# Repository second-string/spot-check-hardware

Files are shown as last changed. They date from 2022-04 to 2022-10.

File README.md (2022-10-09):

# spot-check-hardware
Board design and assembly files for the Spot Check project

* Firmware repo: https://github.com/dot4qu/spot-check-firmware
* Backend API repo: https://github.com/dot4qu/spot-check-api
* Configuration iOS app repo: https://github.com/dot4qu/spot-check-ios

More pictures of overall enclosure and project found in the firmware repo.

## Rev 3.1

**Use this version!!**

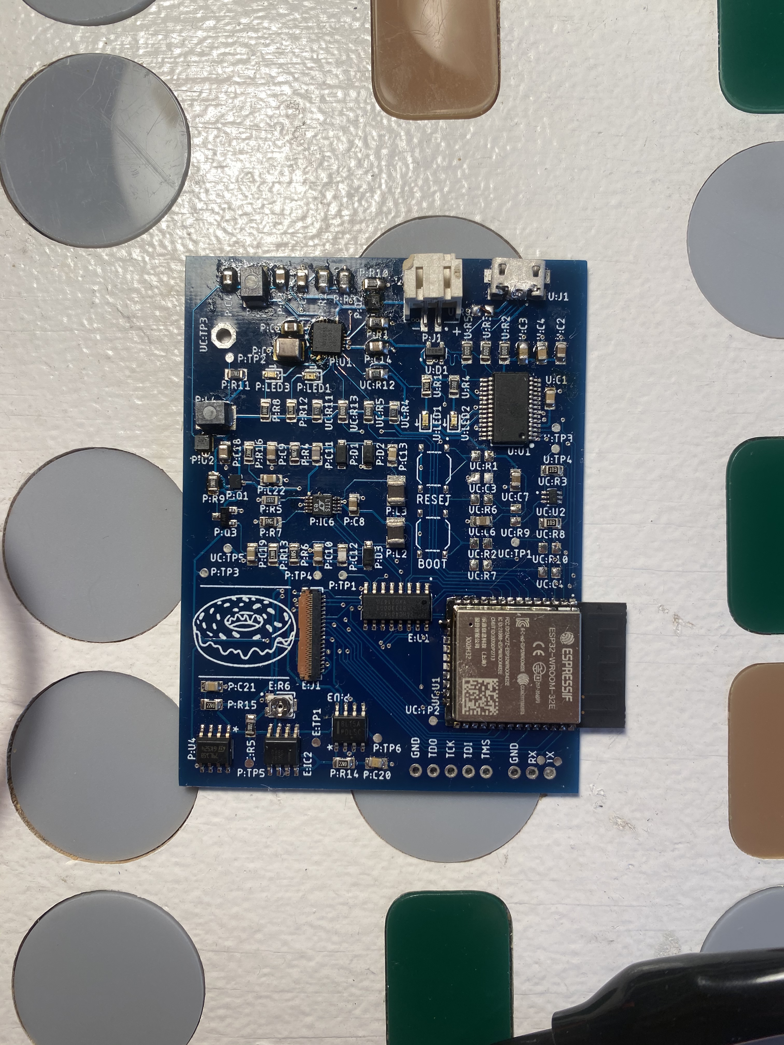
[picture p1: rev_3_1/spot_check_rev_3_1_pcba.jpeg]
Spot Check rev. 3.1 PCBA


Fixes the issues in rev 3, mainly:
* Adds the missing capacitor between BTST and SW output of BQ24196 battery charger
* Switches the ESP footprint to the correct ESP32-WROVER footprint (all I/O on sides and longer length, no I/O on bottom like WROOM)
* Add 1uF cap acros ESP32 EN pin to slow its rise time enough to allow DTR/RTS auto-programming circuit to work
* Removed all the now-unneccesary zero ohm resistors

## Rev 3

_See rev. 3.1 PCBA, only minor differences_

Huge rework and addition from rev 2. Adds:
* USB to UART IC for power and programming instead of UART header (still on board for backup use if needed)
* Battery charger IC for supporting battery powered operation instead of wall outlet power
* Integrated e-ink driver circuit using shift register, boost converter to produce +22/-20V, additional regulators to filter to +/-15V, and a small-pitch FPC connector to connect to e-ink display
* Switch to ESP32-WROVER for additional on-module SRAM needed to run `epdiy` open source e-ink firmware

## Rev 2

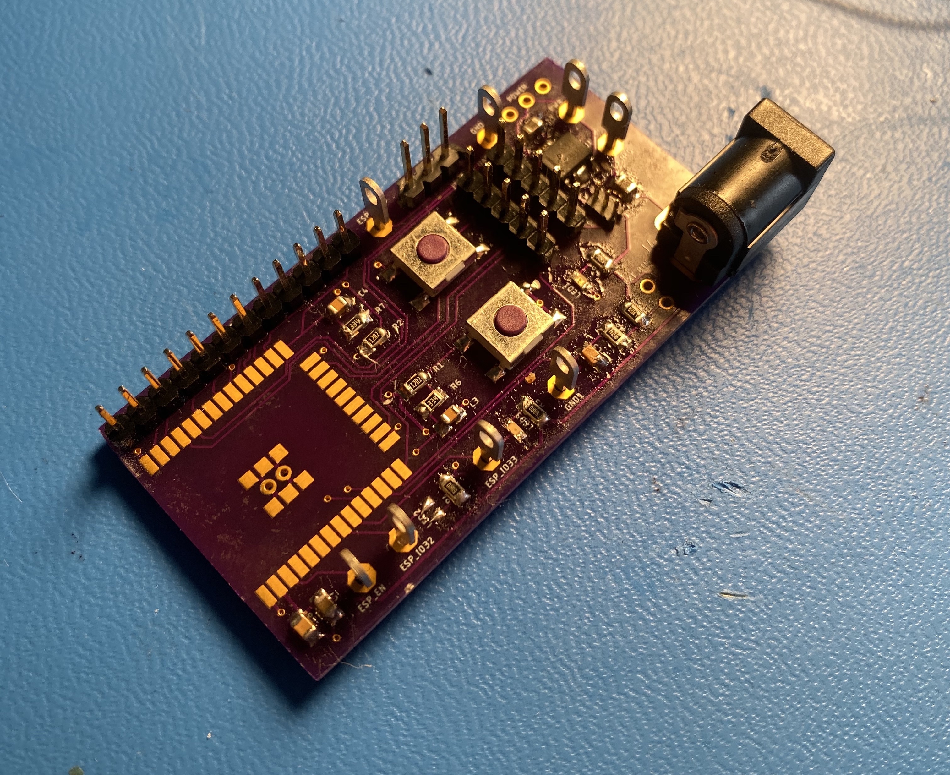
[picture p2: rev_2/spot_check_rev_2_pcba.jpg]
Spot Check rev. 2 PCBA


The main, working revision for properly displaying text on an LED strip ticker with only an ESP32 driving everything. Powered from a 5V 1.5A+ barrel jack.

## Rev 1

Spot Check rev. 1 PCBA

The OG. This was an ESP chip that ran the main application logic that then communicated serially over UART to an ATMega328p to display the text on the LED strips (as the LED text libraries are only developed for Arduino). Zero support for this, I don't think I ever got the serial communication working super well since I had no protocol and the ESP would spew nonsense signals on boot. Oh to be young and naive again (just kidding I still am).

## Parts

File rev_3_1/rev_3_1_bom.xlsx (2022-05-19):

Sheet: BOM
Spot Check
Project: | Spot Check |  |  |  | Do not have enough in stock
Revision | 3 |  |  |  | Have exactly the right amount in stock
File created: | 2022-02-05 |  |  |  | Have extra stock
Bill of Materials
Mfg. Part Number | Description | Source | Link | Current stock | Have enough | Quantity | Measurement | Unit Price | Total Price | Filtered search URL | Notes
ED060SC4 | e-ink display | ebay |  |  | -1 | 1 |  | $25.00 | $25.00
SKU: 9067000191-0 | 2000MAH 1S/1C LiPo w/ 2 pin JST-PH conn. | HobbyKing | https://hobbyking.com/en_us/turnigy-2000mah-1s-1c-lipoly-w-2-pin-jst-ph-connector.html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 |  | -1 | 1 |  | $4.53 | $4.53 | Second hobbyking order: https://hobbyking.com/en_us/turnigy-1200mah-1s-1c-lipoly-w-2-pin-jst-ph-connector.html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 Another option (expensive, w/ TS & UL cert): https://www.batteryspace.com/Polymer-Li-Ion-battery-3.7V-2000mAh-7.4-Wh-with-10K-NTC.aspx
BQ24196RGER | Battery charger IC VQFN | Digikey | https://www.digikey.com/en/products/detail/texas-instruments/BQ24196RGER/3902488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 |  | -1 | 1 |  | $4.04 | $4.04 | https://www.ti.com/power-management/battery-management/charger-ics/products.html | Have second pin-compatible alternate in stock too
TPS62082DSGR | 3.3V buck | Digikey | https://www.digikey.com/en/products/detail/texas-instruments/TPS62082DSGR/2797959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 |  | -1 | 1 |  | $1.73 | $1.73
MC78L15ACDR2G | 15V linear reg | Digikey | https://www.digikey.com/en/products/detail/onsemi/MC78L15ACDR2G/919359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 |  | -1 | 1 |  | $0.53 | $0.53
L79L15ABD13TR | neg 15 linear reg | Digikey | https://www.digikey.com/en/products/detail/stmicroelectronics/L79L15ABD13TR/1038332 |  | -1 | 1 |  | $0.51 | $0.51 | https://www.digikey.com/en/products/filter/pmic-voltage-regulators-linear/699 | Main desired part (OOS, alternative in BOM): MC79L15ACDR2G/MC79L15ABDR2G
SSM3J132TU,LF | P-channel FET | Digikey | https://www.digikey.com/en/products/detail/toshiba-semiconductor-and-storage/SSM3J132TU-LF/6198762 |  | -2 | 2 |  | $0.54 | $1.08 | https://www.digikey.com/en/products/filter/transistors-fets-mosfets-single/278 | This could be less $, went for super low Rds for low V burn from batt
ESP32-WROVER-32E | ESP32 WROVER 8MB flash w/ PCB antenna | Digikey | https://www.digikey.com/en/products/detail/espressif-systems/ESP32-WROVER-E-N8R8/11613126 |  | -1 | 1 |  | $3.60 | $3.60
MBR0520LT1G | Boost converter diodes | Digikey | https://www.digikey.com/en/products/detail/onsemi/MBR0520LT1G/918574?s=N4IgTCBcDaILICEBKAGArGFAZAKgRgHEQBdAXyA |  | -3 | 3 |  | $0.36 | $1.08
DRTR5V0U2SR-7 | USB TVS package | Digikey | https://www.digikey.com/en/products/detail/diodes-incorporated/DRTR5V0U2SR-7/4402528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 |  | -1 | 1 |  | $0.40 | $0.40
LM358DR | 2 channel op-amp | Digikey | https://www.digikey.com/en/products/detail/texas-instruments/LM358DR/276658 |  | -1 | 1 |  | $0.69 | $0.69 |  | Identical part (diff. distrib., more $) if sold out: https://www.digikey.com/en/products/detail/rohm-semiconductor/LM358DR/1878967
LT1945EMS#PBF | Boost converter | Digikey | https://www.digikey.com/en/products/detail/analog-devices-inc/LT1945EMS-PBF/890537 |  | -1 | 1 |  | $6.21 | $6.21 |  | This price is fucked, alternate part or other supplier
PTS526 SK15 SMTR2 LFS | SMD button | Digikey | https://www.digikey.com/en/products/detail/c-k/PTS526-SK15-SMTR2-LFS/10056626 |  | -2 | 2 |  | $0.11 | $0.22 | https://www.digikey.com/en/products/filter/tactile-switches/197
74HC4094D,653 | Shift and store register | Digikey | https://www.digikey.com/en/products/detail/nexperia-usa-inc/74HC4094D-653/946727 |  | -1 | 1 |  | $0.52 | $0.52
FT232RL | USB to serial transceiver | ebay |  |  | -1 | 1 |  | $3.00 | $3.00
MMBT3904,215 | NPN BJT | Digikey | https://www.digikey.com/en/products/detail/nexperia-usa-inc/MMBT3904-215/1156599 |  | -1 | 1 |  | $0.12 | $0.12
BC848CDW1T1G | 2 NPN BJT package | Digikey | https://www.digikey.com/en/products/detail/onsemi/BC848CDW1T1G/1476035 |  | -1 | 1 |  | $0.26 | $0.26
10118192-0002LF | USB micro female SMT right-angle connector | Digikey | https://www.digikey.com/en/products/detail/amphenol-icc-fci/10118192-0002LF/6817756 |  | -1 | 1 |  | $0.44 | $0.44 |  | Alternate: https://www.digikey.com/en/products/detail/amphenol-cs-fci/10118192-0001LF/2785387
FH26W-39S-0.3SHW(60) | 39 pin SMD flex connector | Digikey | https://www.digikey.com/en/products/detail/hirose-electric-co-ltd/FH26W-39S-0-3SHW-60/5132503 |  | -1 | 1 |  | $1.92 | $1.92
JST-PHR-2 | Male 2-pin JST connector | Digikey | https://www.digikey.com/en/products/detail/jst-sales-america-inc/S2B-PH-K-S-LF-SN/926626 |  | -1 | 1 |  | $0.17 | $0.17 | sold out everwhere
150060GS75000 | 0603 green LED for BQ | Digikey | https://www.digikey.com/en/products/detail/würth-elektronik/150060GS75000/4489898 |  | -1 | 1 |  | $0.15 | $0.15 | https://www.digikey.com/en/products/filter/led-indication-discrete/105
150060RS75000 | 0603 red LED for BQ | Digikey | https://www.digikey.com/en/products/detail/würth-elektronik/150060RS75000/4489901 |  | -1 | 1 |  | $0.15 | $0.15
150060BS75000 | 0603 blue LED for FT232 | Digikey | https://www.digikey.com/en/products/detail/würth-elektronik/150060BS75000/4489895 |  | -1 | 1 |  | $0.16 | $0.16
150060YS75000 | 0603 yellow LED for FT232 | Digikey | https://www.digikey.com/en/products/detail/würth-elektronik/150060YS75000/4489909 |  | -1 | 1 |  | $0.15 | $0.15
PREC040SAAN-RC | Male 0.1" 40 position header (default unpop.) | Digikey | https://www.digikey.com/en/products/detail/sullins-connector-solutions/PREC040SAAN-RC/2774814 |  | -1 | 1 |  | $0.51 | $0.51 | https://www.digikey.com/en/products/filter/rectangular-connectors-headers-male-pins/314 | Need 8 to fully populate JTAG and backup UART breakout
CL21B104KBCNFNC | 0.1uF 0805 ceramic capacitor for max 22V | Digikey | https://www.digikey.com/en/products/detail/samsung-electro-mechanics/CL21B104KBCNFNC/3888102 |  | -5 | 5 |  | $0.10 | $0.50 | ^
CL21B334KBFNNNE | 0.33uF 0805 ceramic capacitor for max 22V | Digikey | https://www.digikey.com/en/products/detail/samsung-electro-mechanics/CL21B334KBFNNNE/3886781 |  | -2 | 2 |  | $0.10 | $0.20 | https://www.digikey.com/en/products/filter/ceramic-capacitors/60
CL21B105KAFNNNE | 1uF 0805 ceramic capacitor for max 5V | Digikey | https://www.digikey.com/en/products/detail/samsung-electro-mechanics/CL21B105KAFNNNE/3886724 |  | -3 | 3 |  | $0.10 | $0.30 | https://www.digikey.com/en/products/filter/ceramic-capacitors/60
CL21B105KBFNNNG | 1uF 0805 ceramic capacitor for max 22V | Digikey | https://www.digikey.com/en/products/detail/samsung-electro-mechanics/CL21B105KBFNNNG/3894467 |  | -2 | 2 |  | $0.12 | $0.24 | https://www.digikey.com/en/products/filter/ceramic-capacitors/60
CC0805BRNPO9BN4R7 | 4.7pF 0805 ceramic capacitor for max 22V | Digikey | https://www.digikey.com/en/products/detail/yageo/CC0805BRNPO9BN4R7/5883879 |  | -1 | 1 |  | $0.17 | $0.17
CL21A475KAQNNNG | 4.7uF 0805 ceramic capacitor for max 5V | Digikey | https://www.digikey.com/en/products/detail/samsung-electro-mechanics/CL21A475KAQNNNG/3894439 |  | -3 | 3 |  | $0.11 | $0.33 | https://www.digikey.com/en/products/filter/ceramic-capacitors/60
CGA6P3X7R1E685K250AB | 6.8uF 0805 ceramic capacitor for max 5V | Digikey | https://www.digikey.com/en/products/detail/tdk-corporation/CGA6P3X7R1E685K250AB/2443197 |  | -1 | 1 |  | $0.70 | $0.70 | https://www.digikey.com/en/products/filter/ceramic-capacitors/60
CL21B103KAANNNC | 10nF 0805 ceramic capacitor for max 5V | Digikey | https://www.digikey.com/en/products/detail/samsung-electro-mechanics/CL21B103KAANNNC/3888092 |  | -1 | 1 |  | $0.10 | $0.10 | https://www.digikey.com/en/products/filter/ceramic-capacitors/60
CL21A106KOQNNNE | 10uF 0805 ceramic capacitor for max 3V3 | Digikey | https://www.digikey.com/en/products/detail/samsung-electro-mechanics/CL21A106KOQNNNE/3886754 |  | -3 | 3 |  | $0.11 | $0.33 | https://www.digikey.com/en/products/filter/ceramic-capacitors/60
CL21A226KOQNNNG | 22uF 0805 ceramic capacitor for max 3V3 | Digikey | https://www.digikey.com/en/products/detail/samsung-electro-mechanics/CL21A226KOQNNNG/3894433 |  | -2 | 2 |  | $0.35 | $0.70 | https://www.digikey.com/en/products/filter/ceramic-capacitors/60
CL21C101JBANFNC | 100pF 0805 ceramic capacitor for max 22V | Digikey | https://www.digikey.com/en/products/detail/samsung-electro-mechanics/CL21C101JBANFNC/3888226 |  | -1 | 1 |  | $0.10 | $0.10
CL21B473KCFNNNE | 47nF 0805 ceramic capacitor for max 5V | Digikey | https://www.digikey.com/en/products/detail/samsung-electro-mechanics/CL21B473KCFNNNE/3888618 |  | -1 | 1 |  | $0.10 | $0.10 | https://www.digikey.com/en/products/filter/ceramic-capacitors/60
TC33X-1-103E | 10k ohm SMT potentiometer | Digikey | https://www.digikey.com/en/products/detail/bourns-inc/TC33X-1-103E/2566867 |  | -1 | 1 |  | $0.26 | $0.26 | https://www.digikey.com/en/products/detail/nidec-copal-electronics/ST4ETB103/738213 | Can just replace footprint with correctly sized resistor for screen's VCOM in the future
RMCF0805FT1K20 | 1.2k ohm 0805 resistor | Digikey | https://www.digikey.com/en/products/detail/stackpole-electronics-inc/RMCF0805FT1K20/1760625 |  | -2 | 2 |  | $0.10 | $0.20 | https://www.digikey.com/en/products/filter/chip-resistor-surface-mount/52
RMCF0805FT2K20 | 2.2k ohm 0805 resistor | Digikey | https://www.digikey.com/en/products/detail/stackpole-electronics-inc/RMCF0805FT2K20/1760345 |  | -1 | 1 |  | $0.10 | $0.10 | https://www.digikey.com/en/products/filter/chip-resistor-surface-mount/52
RMCF0805JT1M00 | 1M ohm 0805 resistor | Digikey | https://www.digikey.com/en/products/detail/stackpole-electronics-inc/RMCF0805JT1M00/1757878 |  | -1 | 1 |  | $0.10 | $0.10 | https://www.digikey.com/en/products/filter/chip-resistor-surface-mount/52
RMCF0805JT4K70 | 4.7k ohm 0805 resistor | Digikey | https://www.digikey.com/en/products/detail/stackpole-electronics-inc/RMCF0805JT4K70/1757774 |  | -3 | 3 |  | $0.10 | $0.30 | https://www.digikey.com/en/products/filter/chip-resistor-surface-mount/52
RMCF0805JT10K0 | 10k ohm 0805 resistor | Digikey | https://www.digikey.com/en/products/detail/stackpole-electronics-inc/RMCF0805JT10K0/1757762 |  | -2 | 2 |  | $0.10 | $0.20 | https://www.digikey.com/en/products/filter/chip-resistor-surface-mount/52
RMCF0805FT12K0 | 12k ohm 0805 resistor | Digikey | https://www.digikey.com/en/products/detail/stackpole-electronics-inc/RMCF0805FT12K0/1760674 |  | -2 | 2 |  | $0.10 | $0.20 | https://www.digikey.com/en/products/filter/chip-resistor-surface-mount/52
RMCF0805FT20K0 | 20k ohm 0805 resistor | Digikey | https://www.digikey.com/en/products/detail/stackpole-electronics-inc/RMCF0805FT20K0/1760314 |  | -1 | 1 |  | $0.10 | $0.10 | https://www.digikey.com/en/products/filter/chip-resistor-surface-mount/52
RMCF0805FT22R0 | 22 ohm 0805 resistor | Digikey | https://www.digikey.com/en/products/detail/stackpole-electronics-inc/RMCF0805FT22R0/1712862 |  | -4 | 4 |  | $0.10 | $0.40 | https://www.digikey.com/en/products/filter/chip-resistor-surface-mount/52
RMCF0805FT26K1 | 26.1k ohm 0805 resistor | Digikey | https://www.digikey.com/en/products/detail/stackpole-electronics-inc/RMCF0805FT26K1/1760232 |  | -2 | 2 |  | $0.10 | $0.20 | https://www.digikey.com/en/products/filter/chip-resistor-surface-mount/52
RMCF0805FT59K0 | 59k ohm 0805 resistor | Digikey | https://www.digikey.com/en/products/detail/stackpole-electronics-inc/RMCF0805FT59K0/1760440 |  | -1 | 1 |  | $0.10 | $0.10 | https://www.digikey.com/en/products/filter/chip-resistor-surface-mount/52
RMCF0805FT178K | 178k ohm 0805 resistor | Digikey | https://www.digikey.com/en/products/detail/stackpole-electronics-inc/RMCF0805FT178K/1712751 |  | -1 | 1 |  | $0.10 | $0.10 | https://www.digikey.com/en/products/filter/chip-resistor-surface-mount/52
RMCF0805FT270R | 270 ohm 0805 resistor | Digikey | https://www.digikey.com/en/products/detail/stackpole-electronics-inc/RMCF0805FT270R/1760099 |  | -1 | 1 |  | $0.10 | $0.10 | https://www.digikey.com/en/products/filter/chip-resistor-surface-mount/52
RMCF0805FT330R | 330 ohm 0805 resistor | Digikey | https://www.digikey.com/en/products/detail/stackpole-electronics-inc/RMCF0805FT330R/1760484 |  | -1 | 1 |  | $0.10 | $0.10 | https://www.digikey.com/en/products/filter/chip-resistor-surface-mount/52
RMCF0805FT330K | 330k ohm 0805 resistor | Digikey | https://www.digikey.com/en/products/detail/stackpole-electronics-inc/RMCF0805FT330K/1760482 |  | -2 | 2 |  | $0.10 | $0.20 | https://www.digikey.com/en/products/filter/chip-resistor-surface-mount/52
RMCF0805FT402K | 402k ohm 0805 resistor | Digikey | https://www.digikey.com/en/products/detail/stackpole-electronics-inc/RMCF0805FT402K/1713128 |  | -1 | 1 |  | $0.10 | $0.10 | https://www.digikey.com/en/products/filter/chip-resistor-surface-mount/52
RMCF0805JG470R | 470 ohm 0805 resistor | Digikey | https://www.digikey.com/en/products/detail/stackpole-electronics-inc/RMCF0805JG470R/1712020 |  | -1 | 1 |  | $0.10 | $0.10 | https://www.digikey.com/en/products/filter/chip-resistor-surface-mount/52
CBC3225T220KR | 22uH 1280 10% 580mA inductor | Digikey | https://www.digikey.com/en/products/detail/taiyo-yuden/CBC3225T220KR/2763319 |  | -2 | 2 |  | $0.30 | $0.60 | https://www.digikey.com/en/products/filter/fixed-inductors/71
B82432T1222K000 | 2.2uH SMD-2 10% 1A inductor | Digikey | https://www.digikey.com/en/products/detail/walsin-technology-corporation/WLPH201610M2R2PP/14563776 |  | -1 | 1 |  | $0.11 | $0.11 | https://www.digikey.com/en/products/filter/fixed-inductors/71
B82432T1102K000 | 1uH SMD-2 10% 1.3A inductor | Digikey | https://www.digikey.com/en/products/detail/walsin-technology-corporation/WLPH201610M1R0PS/14563835 |  | -1 | 1 |  | $0.14 | $0.14 | https://www.digikey.com/en/products/filter/fixed-inductors/71
 |  |  |  |  |  |  |  |  | $0.00
 |  |  |  |  |  |  |  |  | $0.00
 |  |  |  |  |  |  |  |  | $0.00
 |  |  |  |  |  |  |  |  | $0.00
 |  |  |  |  |  |  |  | Totals: | $62.30

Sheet: Eagle-generated BOM
Part | Value | Device | Package | Description | ARROW_PART_NUMBER | ARROW_PRICE-STOCK | AVAILABILITY | CIIVA_IDS | COMPONENT_LINK_1_DESCRIPTION | COMPONENT_LINK_1_URL | COMPONENT_LINK_3_DESCRIPTION | COMPONENT_LINK_3_URL | DATASHEET | DATASHEET_VERSION | DESCRIPTION | FOOTPRINT_VARIANT_NAME_0 | FOOTPRINT_VARIANT_NAME_1 | FOOTPRINT_VARIANT_NAME_2 | HEIGHT | IMPORTED | IMPORTED_FROM | IMPORT_TS | MANUFACTURER_NAME | MANUFACTURER_PART_NUMBER | MF | MOUNTING_TECHNOLOGY | MOUSER_PART_NUMBER | MOUSER_PRICE-STOCK | MP | MPN | NUMBER_OF_OUTPUTS | PACKAGE | PACKAGE_DESCRIPTION | PACKAGE_VERSION | POPULARITY | PREFIX | PRICE | PURCHASE-URL | RELEASE_DATE | ROHS | SPICEPREFIX | TP_SIGNAL_NAME | VAULT_GUID | VAULT_REVISION | VIN_MAXV | VIN_MINV
U:J1 | 10118192-0002LF | 10118192-0002LF | AMPHENOL_10118192-0002LF | USB - micro B USB 2.0 Receptacle Connector 5 Position Surface Mount, Right Angle Check availability |  |  | In Stock |  |  |  |  |  |  |  | Micro USB 2.0, Input Output Connectors, B TYPE RECEPTACLE without flange |  |  |  |  |  |  |  |  |  | Amphenol ICC (FCI) |  |  |  | 10118192-0002LF |  |  | None |  |  |  |  | None | https://pricing.snapeda.com/search/part/10118192-0002LF/?ref=eda
P:C13 | 0.1uF | C-EUC0805 | C0805 | CAPACITOR, European symbol |  |  |  |  |  |  |  |  |  |  |  |  |  |  |  |  |  |  |  |  |  |  |  |  |  |  |  |  |  |  | 88 |  |  |  |  |  | C
P:C20 | 0.1uF | C-EUC0805 | C0805 | CAPACITOR, European symbol |  |  |  |  |  |  |  |  |  |  |  |  |  |  |  |  |  |  |  |  |  |  |  |  |  |  |  |  |  |  | 88 |  |  |  |  |  | C
P:C21 | 0.1uF | C-EUC0805 | C0805 | CAPACITOR, European symbol |  |  |  |  |  |  |  |  |  |  |  |  |  |  |  |  |  |  |  |  |  |  |  |  |  |  |  |  |  |  | 88 |  |  |  |  |  | C
P:C19 | 0.33uF | C-EUC0805 | C0805 | CAPACITOR, European symbol |  |  |  |  |  |  |  |  |  |  |  |  |  |  |  |  |  |  |  |  |  |  |  |  |  |  |  |  |  |  | 88 |  |  |  |  |  | C
P:C22 | 0.33uF | C-EUC0805 | C0805 | CAPACITOR, European symbol |  |  |  |  |  |  |  |  |  |  |  |  |  |  |  |  |  |  |  |  |  |  |  |  |  |  |  |  |  |  | 88 |  |  |  |  |  | C
U:C1 | 100nF | C-EUC0805 | C0805 | CAPACITOR, European symbol |  |  |  |  |  |  |  |  |  |  |  |  |  |  |  |  |  |  |  |  |  |  |  |  |  |  |  |  |  |  | 88 |  |  |  |  |  | C
U:C4 | 100nF | C-EUC0805 | C0805 | CAPACITOR, European symbol |  |  |  |  |  |  |  |  |  |  |  |  |  |  |  |  |  |  |  |  |  |  |  |  |  |  |  |  |  |  | 88 |  |  |  |  |  | C
P:C11 | 100pF | C-EUC0805 | C0805 | CAPACITOR, European symbol |  |  |  |  |  |  |  |  |  |  |  |  |  |  |  |  |  |  |  |  |  |  |  |  |  |  |  |  |  |  | 88 |  |  |  |  |  | C
U:C3 | 10nF | C-EUC0805 | C0805 | CAPACITOR, European symbol |  |  |  |  |  |  |  |  |  |  |  |  |  |  |  |  |  |  |  |  |  |  |  |  |  |  |  |  |  |  | 88 |  |  |  |  |  | C
P:C1 | 10uF | C-EUC0805 | C0805 | CAPACITOR, European symbol |  |  |  |  |  |  |  |  |  |  |  |  |  |  |  |  |  |  |  |  |  |  |  |  |  |  |  |  |  |  | 88 |  |  |  |  |  | C
P:C3 | 10uF | C-EUC0805 | C0805 | CAPACITOR, European symbol |  |  |  |  |  |  |  |  |  |  |  |  |  |  |  |  |  |  |  |  |  |  |  |  |  |  |  |  |  |  | 88 |  |  |  |  |  | C
P:C4 | 10uF | C-EUC0805 | C0805 | CAPACITOR, European symbol |  |  |  |  |  |  |  |  |  |  |  |  |  |  |  |  |  |  |  |  |  |  |  |  |  |  |  |  |  |  | 88 |  |  |  |  |  | C
P:C9 | 1uF | C-EUC0805 | C0805 | CAPACITOR, European symbol |  |  |  |  |  |  |  |  |  |  |  |  |  |  |  |  |  |  |  |  |  |  |  |  |  |  |  |  |  |  | 88 |  |  |  |  |  | C
P:C10 | 1uF | C-EUC0805 | C0805 | CAPACITOR, European symbol |  |  |  |  |  |  |  |  |  |  |  |  |  |  |  |  |  |  |  |  |  |  |  |  |  |  |  |  |  |  | 88 |  |  |  |  |  | C
P:C14 | 1uF | C-EUC0805 | C0805 | CAPACITOR, European symbol |  |  |  |  |  |  |  |  |  |  |  |  |  |  |  |  |  |  |  |  |  |  |  |  |  |  |  |  |  |  | 88 |  |  |  |  |  | C
UC:C2 | 1uF | C-EUC0805 | C0805 | CAPACITOR, European symbol |  |  |  |  |  |  |  |  |  |  |  |  |  |  |  |  |  |  |  |  |  |  |  |  |  |  |  |  |  |  | 88 |  |  |  |  |  | C
UC:C3 | 1uF | C-EUC0805 | C0805 | CAPACITOR, European symbol |  |  |  |  |  |  |  |  |  |  |  |  |  |  |  |  |  |  |  |  |  |  |  |  |  |  |  |  |  |  | 88 |  |  |  |  |  | C
P:C18 | 22uF | C-EUC0805 | C0805 | CAPACITOR, European symbol |  |  |  |  |  |  |  |  |  |  |  |  |  |  |  |  |  |  |  |  |  |  |  |  |  |  |  |  |  |  | 88 |  |  |  |  |  | C
UC:C1 | 22uF | C-EUC0805 | C0805 | CAPACITOR, European symbol |  |  |  |  |  |  |  |  |  |  |  |  |  |  |  |  |  |  |  |  |  |  |  |  |  |  |  |  |  |  | 88 |  |  |  |  |  | C
P:C12 | 4.7pF | C-EUC0805 | C0805 | CAPACITOR, European symbol |  |  |  |  |  |  |  |  |  |  |  |  |  |  |  |  |  |  |  |  |  |  |  |  |  |  |  |  |  |  | 88 |  |  |  |  |  | C
P:C2 | 4.7uF | C-EUC0805 | C0805 | CAPACITOR, European symbol |  |  |  |  |  |  |  |  |  |  |  |  |  |  |  |  |  |  |  |  |  |  |  |  |  |  |  |  |  |  | 88 |  |  |  |  |  | C
P:C8 | 4.7uF | C-EUC0805 | C0805 | CAPACITOR, European symbol |  |  |  |  |  |  |  |  |  |  |  |  |  |  |  |  |  |  |  |  |  |  |  |  |  |  |  |  |  |  | 88 |  |  |  |  |  | C
U:C2 | 4.7uF | C-EUC0805 | C0805 | CAPACITOR, European symbol |  |  |  |  |  |  |  |  |  |  |  |  |  |  |  |  |  |  |  |  |  |  |  |  |  |  |  |  |  |  | 88 |  |  |  |  |  | C
P:C5 | 47nF | C-EUC0805 | C0805 | CAPACITOR, European symbol |  |  |  |  |  |  |  |  |  |  |  |  |  |  |  |  |  |  |  |  |  |  |  |  |  |  |  |  |  |  | 88 |  |  |  |  |  | C
P:L2 | 22uH | L-US | C1210 | INDUCTOR, American symbol
P:L3 | 22uH | L-US | C1210 | INDUCTOR, American symbol
P:C7 | 6.8uF | C-EUC1210 | C1210 | CAPACITOR, European symbol |  |  |  |  |  |  |  |  |  |  |  |  |  |  |  |  |  |  |  |  |  |  |  |  |  |  |  |  |  |  | 0 |  |  |  |  |  | C
E:J1 | FH26W-39S-0.3SHW_05_ | FH26W-39S-0.3SHW_05_ | FH26W39S03SHW05 | FFC & FPC Connectors 39P SMT HORIZ ZIF 1MM HGHT .3MM PITCH |  |  |  |  |  |  |  |  |  |  | FFC & FPC Connectors 39P SMT HORIZ ZIF 1MM HGHT .3MM PITCH |  |  |  | 1mm |  |  |  | Hirose | FH26W-39S-0.3SHW(05) |  |  | 798-FH26W39S03SHW05 | https://www.mouser.co.uk/ProductDetail/Hirose-Connector/FH26W-39S-03SHW05?qs=vnk2wBG9e14RpudjtVAEhA%3D%3D
P:L4 | 1uH | L-USL1812 | L1812 | INDUCTOR, American symbol |  |  |  |  |  |  |  |  |  |  |  |  |  |  |  |  |  |  |  |  |  |  |  |  |  |  |  |  |  |  | 3 |  |  |  |  |  | L
P:L1 | 2.2uH | L-USL1812 | L1812 | INDUCTOR, American symbol |  |  |  |  |  |  |  |  |  |  |  |  |  |  |  |  |  |  |  |  |  |  |  |  |  |  |  |  |  |  | 3 |  |  |  |  |  | L
U:LED2 | 150060BS55040 | 150060VS75000 | LEDC1608X80N | LED,Wurth Elektronik,150060VS75000 Wurth Elektronik 150060VS75000, WL-SMCW Series Green LED, 570 nm, 1608 (0603) Clear, Rectangle Lens SMD Package |  |  | In Stock |  |  |  |  |  |  |  | Green 570nm LED Indication - Discrete 2V 0603 (1608 Metric) |  |  |  |  |  |  |  |  |  | Wurth Elektronik |  |  |  | 150060VS75000 |  |  | None |  |  |  |  | None
P:LED3 | 150060GS55040 | 150060VS75000 | LEDC1608X80N | LED,Wurth Elektronik,150060VS75000 Wurth Elektronik 150060VS75000, WL-SMCW Series Green LED, 570 nm, 1608 (0603) Clear, Rectangle Lens SMD Package |  |  | In Stock |  |  |  |  |  |  |  | Green 570nm LED Indication - Discrete 2V 0603 (1608 Metric) |  |  |  |  |  |  |  |  |  | Wurth Elektronik |  |  |  | 150060VS75000 |  |  | None |  |  |  |  | None
P:LED1 | 150060RS55040 | 150060VS75000 | LEDC1608X80N | LED,Wurth Elektronik,150060VS75000 Wurth Elektronik 150060VS75000, WL-SMCW Series Green LED, 570 nm, 1608 (0603) Clear, Rectangle Lens SMD Package |  |  | In Stock |  |  |  |  |  |  |  | Green 570nm LED Indication - Discrete 2V 0603 (1608 Metric) |  |  |  |  |  |  |  |  |  | Wurth Elektronik |  |  |  | 150060VS75000 |  |  | None |  |  |  |  | None
U:LED1 | 150060YS55040 | 150060VS75000 | LEDC1608X80N | LED,Wurth Elektronik,150060VS75000 Wurth Elektronik 150060VS75000, WL-SMCW Series Green LED, 570 nm, 1608 (0603) Clear, Rectangle Lens SMD Package |  |  | In Stock |  |  |  |  |  |  |  | Green 570nm LED Indication - Discrete 2V 0603 (1608 Metric) |  |  |  |  |  |  |  |  |  | Wurth Elektronik |  |  |  | 150060VS75000 |  |  | None |  |  |  |  | None
P:IC6 | LT1945EMS# | LT1945EMS# | LT1945EMS#PBF_0 | LT-LT1945-MS-10 |  |  |  | 1482624 | Manufacturer URL | http://www.linear.com/ | Package Specification | http://cds.linear.com/docs/en/packaging/05081661_F_MS.pdf | http://cds.linear.com/docs/en/datasheet/1945fa.pdf | Rev. A |  | Level C | Level B | Level A |  | yes | vault | 1521842479 |  |  | Linear Technology | Surface Mount |  |  |  | LT1945EMS#PBF | 2 | MS-10 | 10-Pin Plastic MSOP, Body 3 x 3 mm, Pitch 0.5 mm | Rev. E, 06/2010 |  | U |  |  | 1377814922 | Yes |  |  | B0F6C986-74D1-4265-A3D3-2E2E10FD489A | 624277BD-F6E2-44C2-9180-A8188AE27574 | 15 | 1.2
P:U1 | BQ24196RGER | BQ24196RGER | QFN50P400X400X100-25N | Check prices |  |  | In Stock |  |  |  |  |  |  |  | I2C controlled 2.5A single cell USB/Adaptor charger w/ Narrow VDC Power Path 24-VQFN -40 to 85 |  |  |  |  |  |  |  |  |  | Texas Instruments |  |  |  | BQ24196RGER |  |  | VQFN-24 Texas Instruments |  |  |  |  | None | https://pricing.snapeda.com/search/part/BQ24196RGER/?ref=eda
P:R5 | 27.1k | R-US_R0603 | R0603 | RESISTOR, American symbol |  |  |  |  |  |  |  |  |  |  |  |  |  |  |  |  |  |  |  |  |  |  |  |  |  |  |  |  |  |  | 77 |  |  |  |  |  | R
P:R13 | 22 | R-US_R0805 | R0805 | RESISTOR, American symbol |  |  |  |  |  |  |  |  |  |  |  |  |  |  |  |  |  |  |  |  |  |  |  |  |  |  |  |  |  |  | 85 |  |  |  |  |  | R
P:R14 | 22 | R-US_R0805 | R0805 | RESISTOR, American symbol |  |  |  |  |  |  |  |  |  |  |  |  |  |  |  |  |  |  |  |  |  |  |  |  |  |  |  |  |  |  | 85 |  |  |  |  |  | R
P:R15 | 22 | R-US_R0805 | R0805 | RESISTOR, American symbol |  |  |  |  |  |  |  |  |  |  |  |  |  |  |  |  |  |  |  |  |  |  |  |  |  |  |  |  |  |  | 85 |  |  |  |  |  | R
P:R16 | 22 | R-US_R0805 | R0805 | RESISTOR, American symbol |  |  |  |  |  |  |  |  |  |  |  |  |  |  |  |  |  |  |  |  |  |  |  |  |  |  |  |  |  |  | 85 |  |  |  |  |  | R
U:R1 | 270 | R-US_R0805 | R0805 | RESISTOR, American symbol |  |  |  |  |  |  |  |  |  |  |  |  |  |  |  |  |  |  |  |  |  |  |  |  |  |  |  |  |  |  | 85 |  |  |  |  |  | R
U:R4 | 330 | R-US_R0805 | R0805 | RESISTOR, American symbol |  |  |  |  |  |  |  |  |  |  |  |  |  |  |  |  |  |  |  |  |  |  |  |  |  |  |  |  |  |  | 85 |  |  |  |  |  | R
P:R1 | 470 | R-US_R0805 | R0805 | RESISTOR, American symbol |  |  |  |  |  |  |  |  |  |  |  |  |  |  |  |  |  |  |  |  |  |  |  |  |  |  |  |  |  |  | 85 |  |  |  |  |  | R
P:R10 | 1.2k | R-US_R0805 | R0805 | RESISTOR, American symbol |  |  |  |  |  |  |  |  |  |  |  |  |  |  |  |  |  |  |  |  |  |  |  |  |  |  |  |  |  |  | 85 |  |  |  |  |  | R
P:R12 | 1.2k | R-US_R0805 | R0805 | RESISTOR, American symbol |  |  |  |  |  |  |  |  |  |  |  |  |  |  |  |  |  |  |  |  |  |  |  |  |  |  |  |  |  |  | 85 |  |  |  |  |  | R
UC:R3 | 10k | R-US_R0805 | R0805 | RESISTOR, American symbol |  |  |  |  |  |  |  |  |  |  |  |  |  |  |  |  |  |  |  |  |  |  |  |  |  |  |  |  |  |  | 85 |  |  |  |  |  | R
UC:R8 | 10k | R-US_R0805 | R0805 | RESISTOR, American symbol |  |  |  |  |  |  |  |  |  |  |  |  |  |  |  |  |  |  |  |  |  |  |  |  |  |  |  |  |  |  | 85 |  |  |  |  |  | R
UC:R1 | 12k | R-US_R0805 | R0805 | RESISTOR, American symbol |  |  |  |  |  |  |  |  |  |  |  |  |  |  |  |  |  |  |  |  |  |  |  |  |  |  |  |  |  |  | 85 |  |  |  |  |  | R
UC:R2 | 12k | R-US_R0805 | R0805 | RESISTOR, American symbol |  |  |  |  |  |  |  |  |  |  |  |  |  |  |  |  |  |  |  |  |  |  |  |  |  |  |  |  |  |  | 85 |  |  |  |  |  | R
P:R11 | 178k | R-US_R0805 | R0805 | RESISTOR, American symbol |  |  |  |  |  |  |  |  |  |  |  |  |  |  |  |  |  |  |  |  |  |  |  |  |  |  |  |  |  |  | 85 |  |  |  |  |  | R
P:R6 | 1M | R-US_R0805 | R0805 | RESISTOR, American symbol |  |  |  |  |  |  |  |  |  |  |  |  |  |  |  |  |  |  |  |  |  |  |  |  |  |  |  |  |  |  | 85 |  |  |  |  |  | R
P:R8 | 2.2k | R-US_R0805 | R0805 | RESISTOR, American symbol |  |  |  |  |  |  |  |  |  |  |  |  |  |  |  |  |  |  |  |  |  |  |  |  |  |  |  |  |  |  | 85 |  |  |  |  |  | R
E:R5 | 20k | R-US_R0805 | R0805 | RESISTOR, American symbol |  |  |  |  |  |  |  |  |  |  |  |  |  |  |  |  |  |  |  |  |  |  |  |  |  |  |  |  |  |  | 85 |  |  |  |  |  | R
P:R9 | 20k | R-US_R0805 | R0805 | RESISTOR, American symbol |  |  |  |  |  |  |  |  |  |  |  |  |  |  |  |  |  |  |  |  |  |  |  |  |  |  |  |  |  |  | 85 |  |  |  |  |  | R
UC:R6 | 27.1k | R-US_R0805 | R0805 | RESISTOR, American symbol |  |  |  |  |  |  |  |  |  |  |  |  |  |  |  |  |  |  |  |  |  |  |  |  |  |  |  |  |  |  | 85 |  |  |  |  |  | R
P:R2 | 330k | R-US_R0805 | R0805 | RESISTOR, American symbol |  |  |  |  |  |  |  |  |  |  |  |  |  |  |  |  |  |  |  |  |  |  |  |  |  |  |  |  |  |  | 85 |  |  |  |  |  | R
P:R3 | 330k | R-US_R0805 | R0805 | RESISTOR, American symbol |  |  |  |  |  |  |  |  |  |  |  |  |  |  |  |  |  |  |  |  |  |  |  |  |  |  |  |  |  |  | 85 |  |  |  |  |  | R
P:R4 | 397k | R-US_R0805 | R0805 | RESISTOR, American symbol |  |  |  |  |  |  |  |  |  |  |  |  |  |  |  |  |  |  |  |  |  |  |  |  |  |  |  |  |  |  | 85 |  |  |  |  |  | R
UC:R5 | 4.7k | R-US_R0805 | R0805 | RESISTOR, American symbol |  |  |  |  |  |  |  |  |  |  |  |  |  |  |  |  |  |  |  |  |  |  |  |  |  |  |  |  |  |  | 85 |  |  |  |  |  | R
UC:R7 | 4.7k | R-US_R0805 | R0805 | RESISTOR, American symbol |  |  |  |  |  |  |  |  |  |  |  |  |  |  |  |  |  |  |  |  |  |  |  |  |  |  |  |  |  |  | 85 |  |  |  |  |  | R
UC:R9 | 4.7k | R-US_R0805 | R0805 | RESISTOR, American symbol |  |  |  |  |  |  |  |  |  |  |  |  |  |  |  |  |  |  |  |  |  |  |  |  |  |  |  |  |  |  | 85 |  |  |  |  |  | R
P:R7 | 59k | R-US_R0805 | R0805 | RESISTOR, American symbol |  |  |  |  |  |  |  |  |  |  |  |  |  |  |  |  |  |  |  |  |  |  |  |  |  |  |  |  |  |  | 85 |  |  |  |  |  | R
E:IC2 | LM358DR | LM358D | SO08 | OP AMP also LM158; LM258; LM2904 |  |  |  |  |  |  |  |  |  |  |  |  |  |  |  |  |  |  |  |  |  |  |  |  |  |  |  |  |  |  | 12
P:D1 | MBR0520LT1G | MBR0520LT1G | SOD3716X135N | Rectifier, Schottky Power; Plastic Sod-123; 0.5 a @ +90c If; +125; 20v; 1000 Check prices |  |  | In Stock |  |  |  |  |  |  |  | Diode Schottky 20V 500mA Surface Mount SOD-123 |  |  |  |  |  |  |  |  |  | ON Semiconductor |  |  |  | MBR0520LT1G |  |  | SOD-123-2 ON Semiconductor |  |  |  |  | None | https://pricing.snapeda.com/search/part/MBR0520LT1G/?ref=eda
P:D2 | MBR0520LT1G | MBR0520LT1G | SOD3716X135N | Rectifier, Schottky Power; Plastic Sod-123; 0.5 a @ +90c If; +125; 20v; 1000 Check prices |  |  | In Stock |  |  |  |  |  |  |  | Diode Schottky 20V 500mA Surface Mount SOD-123 |  |  |  |  |  |  |  |  |  | ON Semiconductor |  |  |  | MBR0520LT1G |  |  | SOD-123-2 ON Semiconductor |  |  |  |  | None | https://pricing.snapeda.com/search/part/MBR0520LT1G/?ref=eda
P:D3 | MBR0520LT1G | MBR0520LT1G | SOD3716X135N | Rectifier, Schottky Power; Plastic Sod-123; 0.5 a @ +90c If; +125; 20v; 1000 Check prices |  |  | In Stock |  |  |  |  |  |  |  | Diode Schottky 20V 500mA Surface Mount SOD-123 |  |  |  |  |  |  |  |  |  | ON Semiconductor |  |  |  | MBR0520LT1G |  |  | SOD-123-2 ON Semiconductor |  |  |  |  | None | https://pricing.snapeda.com/search/part/MBR0520LT1G/?ref=eda
E:U1 | CD74HC4094M | CD74HC4094M | SOIC127P600X175-16N | Check availability |  |  | In Stock |  |  |  |  |  |  |  | High Speed CMOS Logic 8-Stage Shift-and-Store Bus Register with 3-Stage Outputs 16-SOIC -55 to 125 |  |  |  |  |  |  |  |  |  | Texas Instruments |  |  |  | CD74HC4094M |  |  | SOIC-16 Texas Instruments |  |  |  |  | None | https://pricing.snapeda.com/search/part/CD74HC4094M/?ref=eda
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

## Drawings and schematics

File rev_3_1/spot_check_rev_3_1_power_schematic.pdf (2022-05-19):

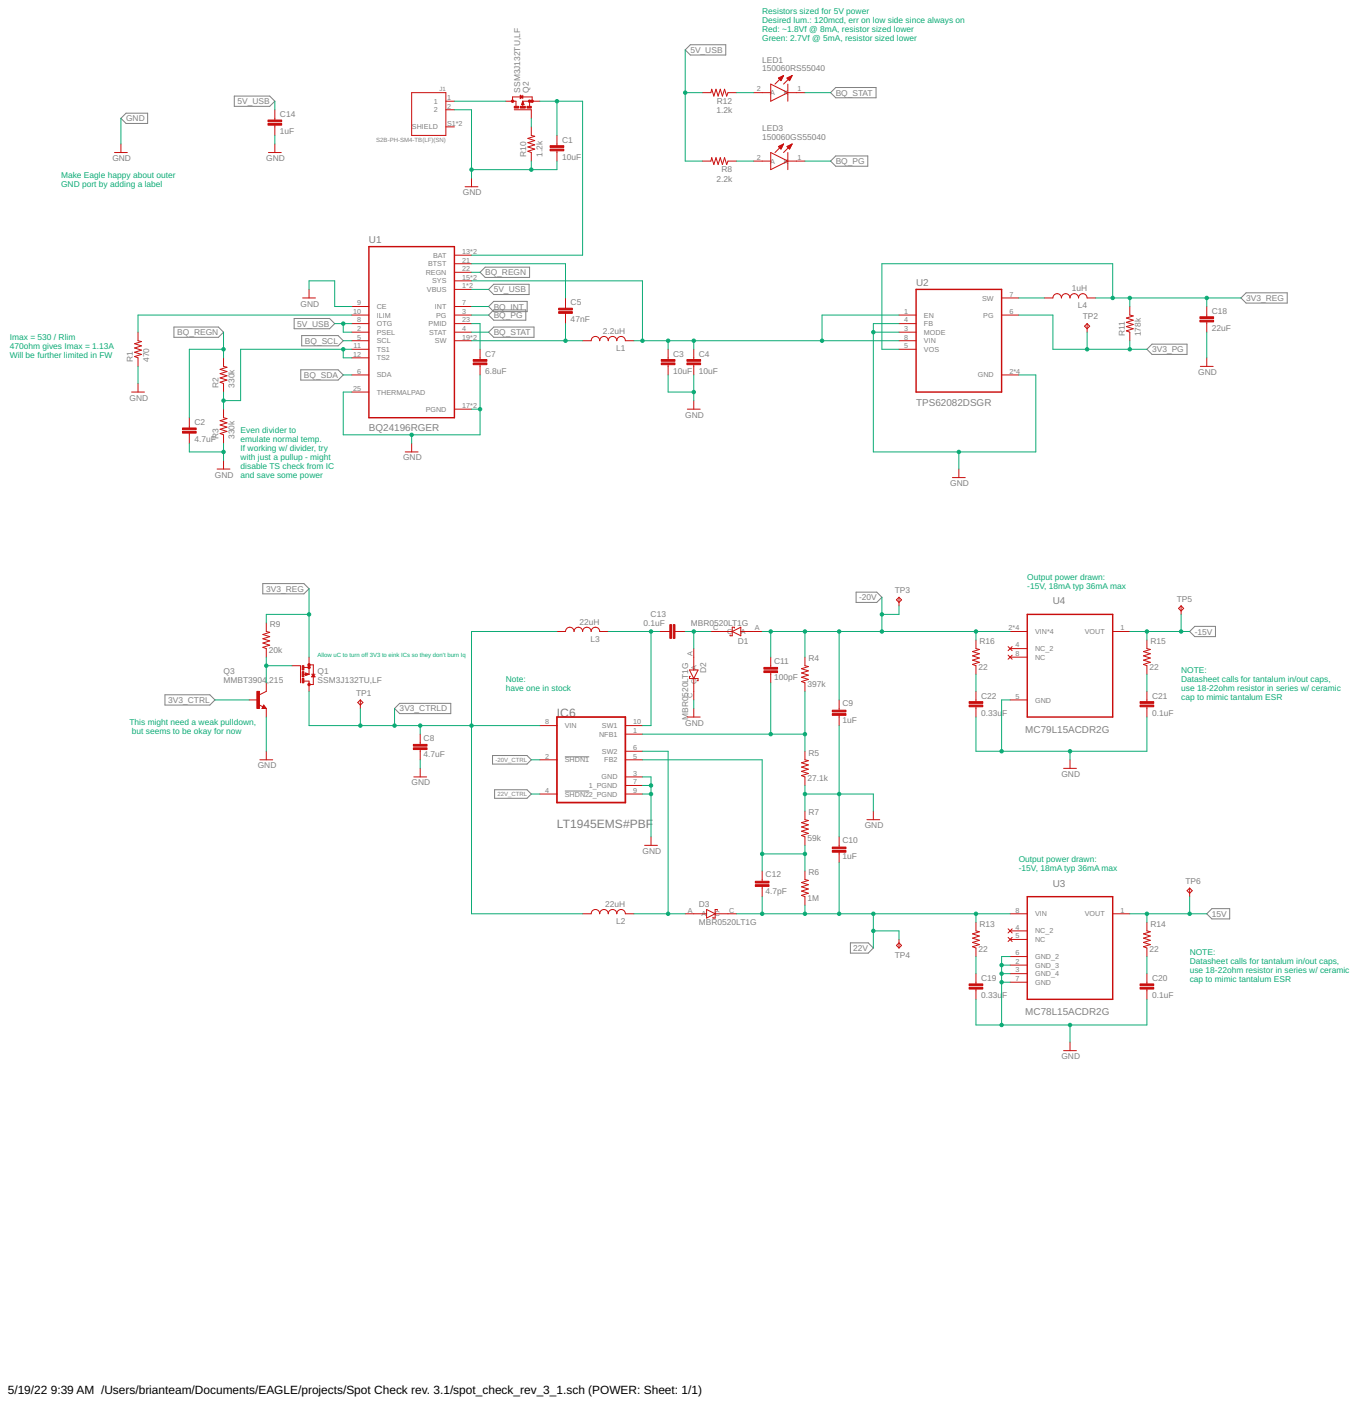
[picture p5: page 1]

Resistors sized for 5V power Desired lum.: 120mcd, err on low side since always on Red: ~1.8Vf @ 8mA, resistor sized lower Green: 2.7Vf @ 5mA, resistor sized lower

Make Eagle happy about outer GND port by adding a label

Imax = 530 / Rlim
470ohm gives Imax = 1.13A
Will be further limited in FW

Even divider to
emulate normal temp.
If working w/ divider, try with just a pullup - might
disable TS check from IC
and save some power

Output power drawn: -15V, 18mA typ 36mA max

Allow uC to turn off 3V3 to eink ICs so they don't burn Iq

NOTE: Datasheet calls for tantalum in/out caps, use 18-22ohm resistor in series w/ ceramic

Note: have one in stock

cap to mimic tantalum ESR

This might need a weak pulldown, but seems to be okay for now

5/19/22 9:39 AM /Users/brianteam/Documents/EAGLE/projects/Spot Check rev. 3.1/spot_check_rev_3_1.sch (POWER: Sheet: 1/1)

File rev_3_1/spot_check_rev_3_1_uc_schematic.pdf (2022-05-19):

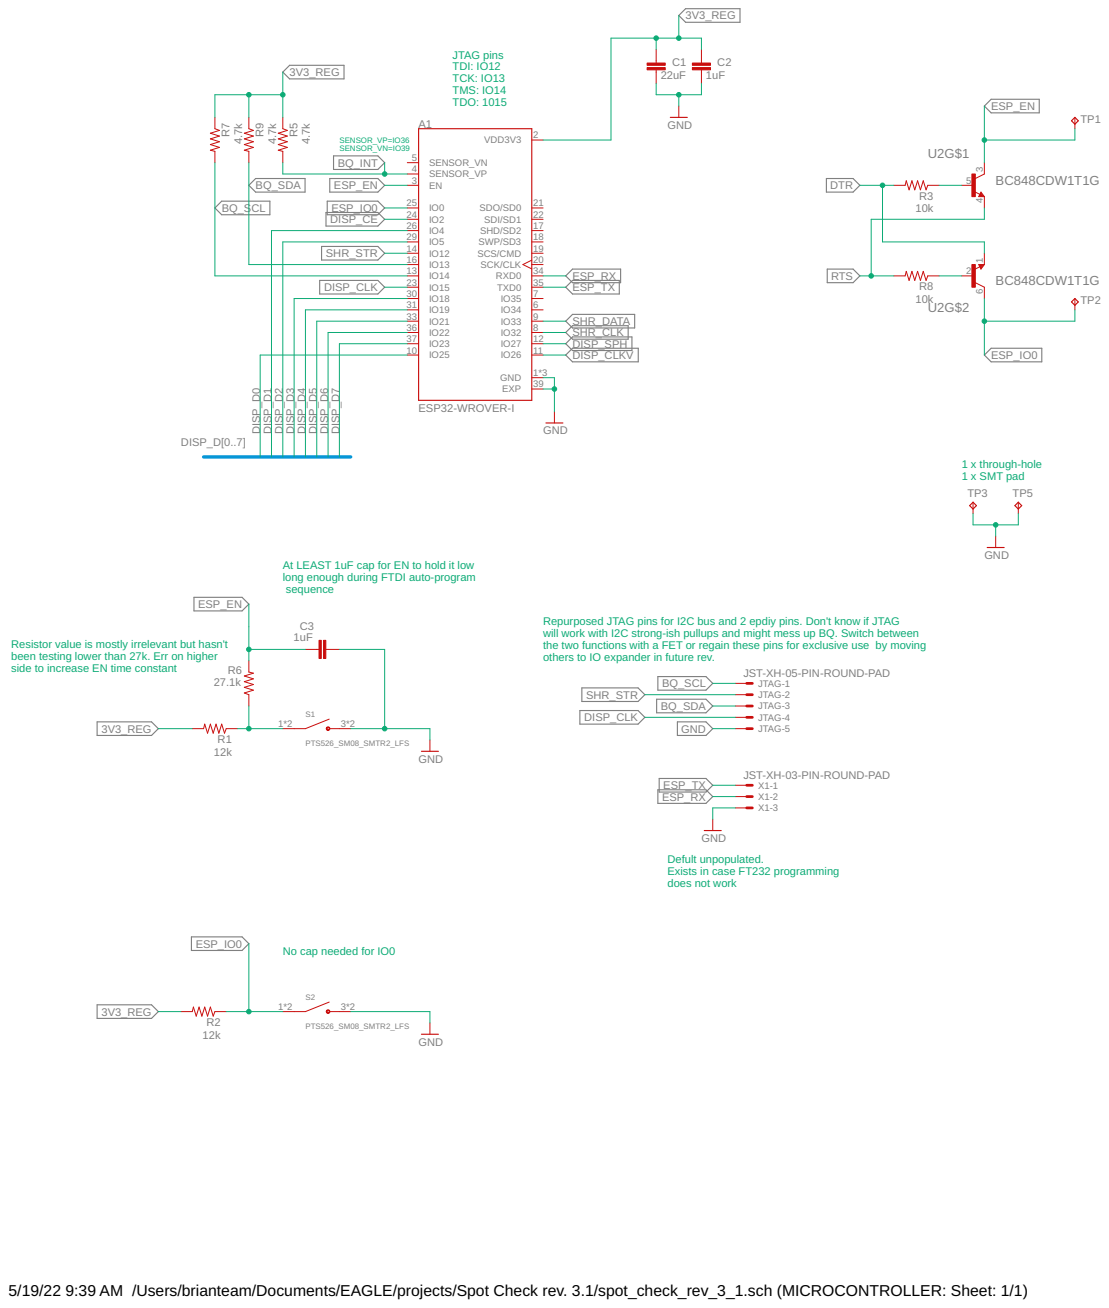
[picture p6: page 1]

23 DISP_CLK

At LEAST 1uF cap for EN to hold it low
long enough during FTDI auto-program

sequence Resistor value is mostly irrelevant but hasn't

Repurposed JTAG pins for I2C bus and 2 epdiy pins. Don't know if JTAG
will work with I2C strong-ish pullups and might mess up BQ. Switch between
the two functions with a FET or regain these pins for exclusive use by moving
others to IO expander in future rev.

been testing lower than 27k. Err on higher side to increase EN time constant

JST-XH-03-PIN-ROUND-PAD

GND
Defult unpopulated. Exists in case FT232 programming
does not work

No cap needed for IO0

5/19/22 9:39 AM /Users/brianteam/Documents/EAGLE/projects/Spot Check rev. 3.1/spot_check_rev_3_1.sch (MICROCONTROLLER: Sheet: 1/1)

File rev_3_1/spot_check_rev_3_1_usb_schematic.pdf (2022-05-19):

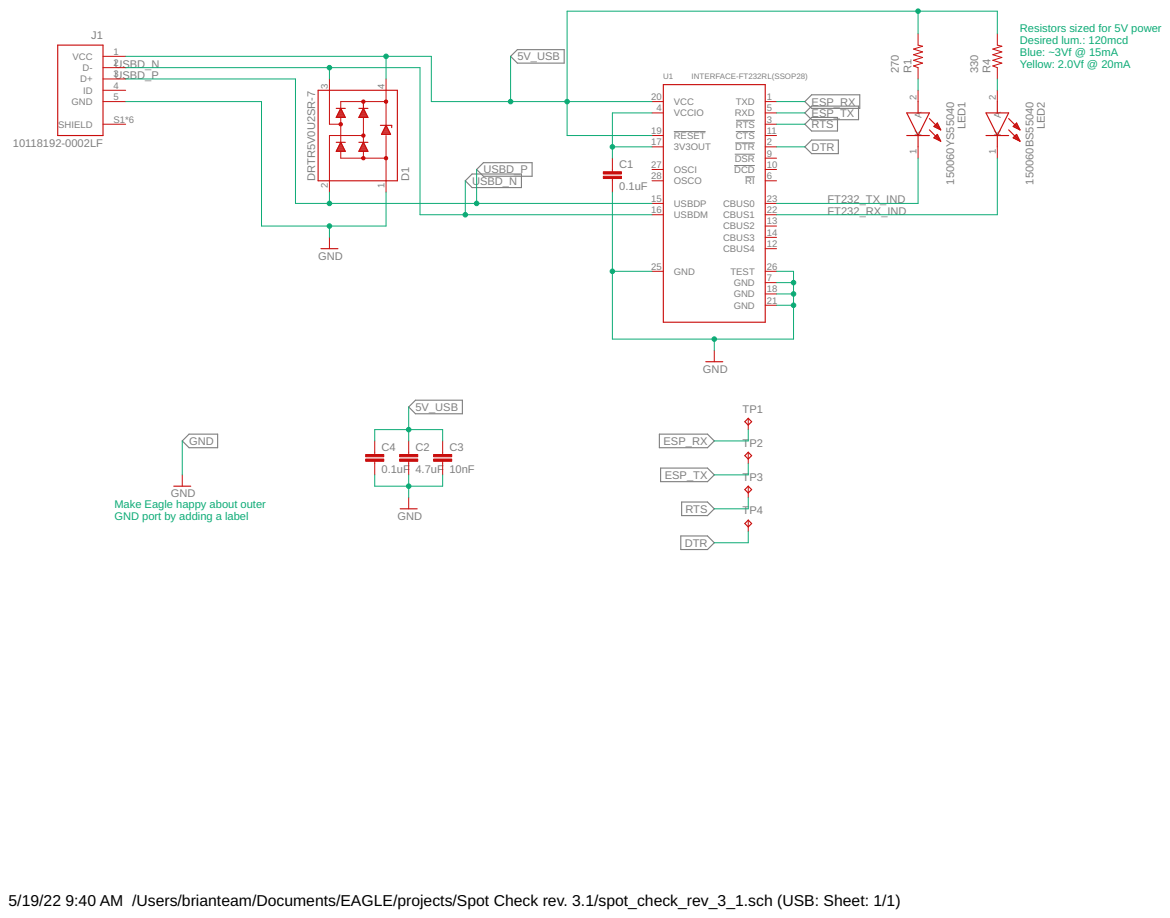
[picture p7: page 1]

Resistors sized for 5V power Desired lum.: 120mcd
Blue: ~3Vf @ 15mA
Yellow: 2.0Vf @ 20mA

Make Eagle happy about outer GND port by adding a label

5/19/22 9:40 AM /Users/brianteam/Documents/EAGLE/projects/Spot Check rev. 3.1/spot_check_rev_3_1.sch (USB: Sheet: 1/1)

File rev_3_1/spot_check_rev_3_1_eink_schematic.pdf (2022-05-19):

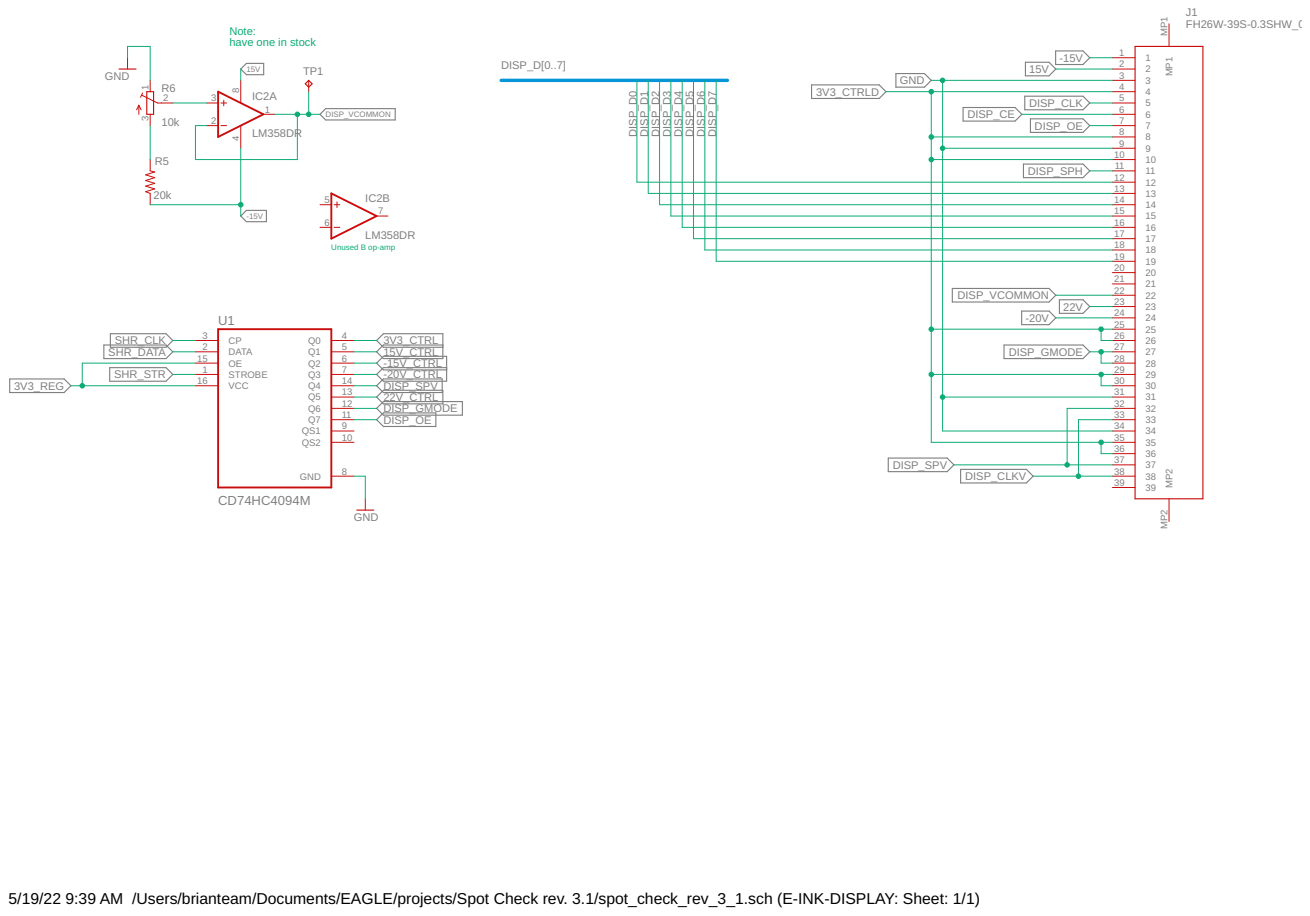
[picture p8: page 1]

Note: have one in stock

11 DISP_SPH 12

13
14
15
16
17
18
19
20 21

35
36

5/19/22 9:39 AM /Users/brianteam/Documents/EAGLE/projects/Spot Check rev. 3.1/spot_check_rev_3_1.sch (E-INK-DISPLAY: Sheet: 1/1)

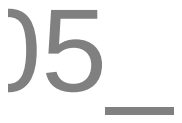
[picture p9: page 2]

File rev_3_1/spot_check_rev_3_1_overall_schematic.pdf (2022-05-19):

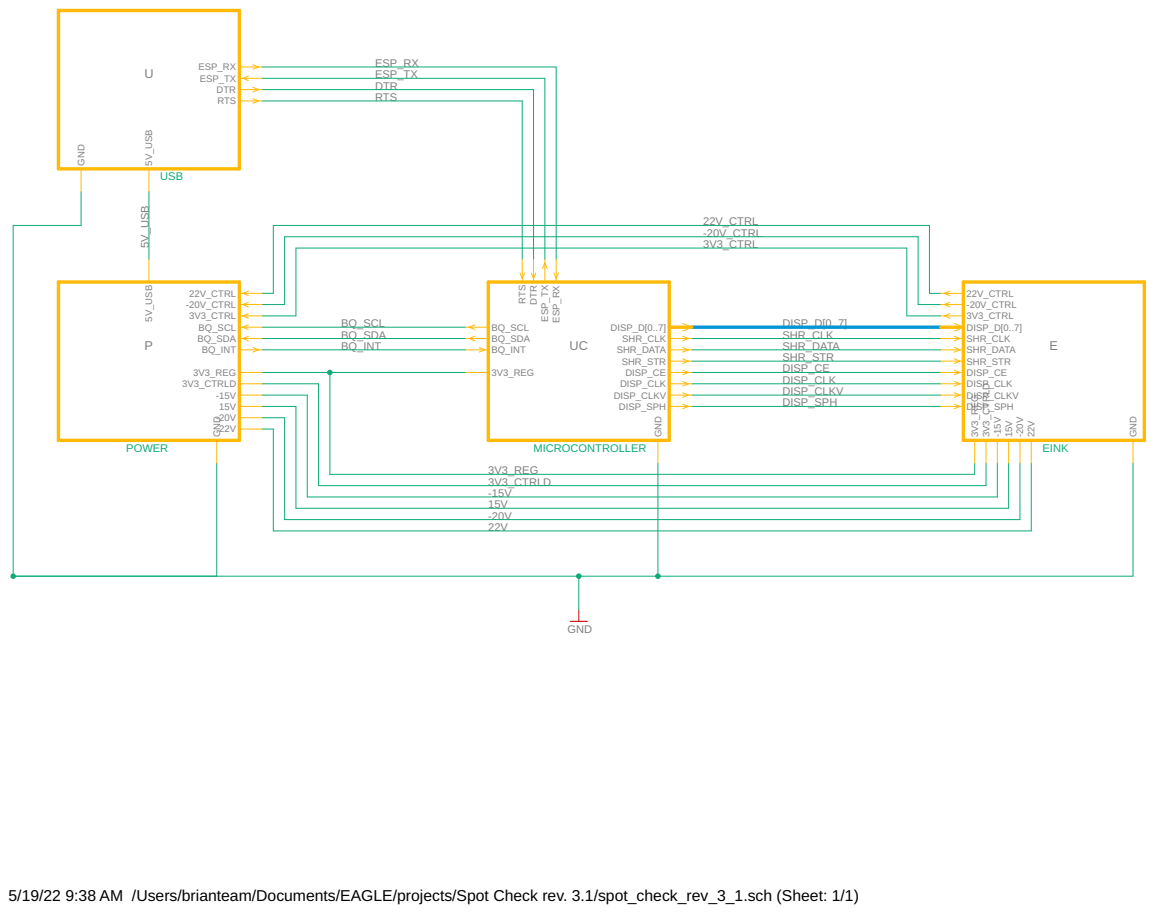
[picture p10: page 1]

-20V_CTRL
3V3_CTRL

BQ_SDA | SHR_CLK
BQ_INT | SHR_DATA

5/19/22 9:38 AM /Users/brianteam/Documents/EAGLE/projects/Spot Check rev. 3.1/spot_check_rev_3_1.sch (Sheet: 1/1)

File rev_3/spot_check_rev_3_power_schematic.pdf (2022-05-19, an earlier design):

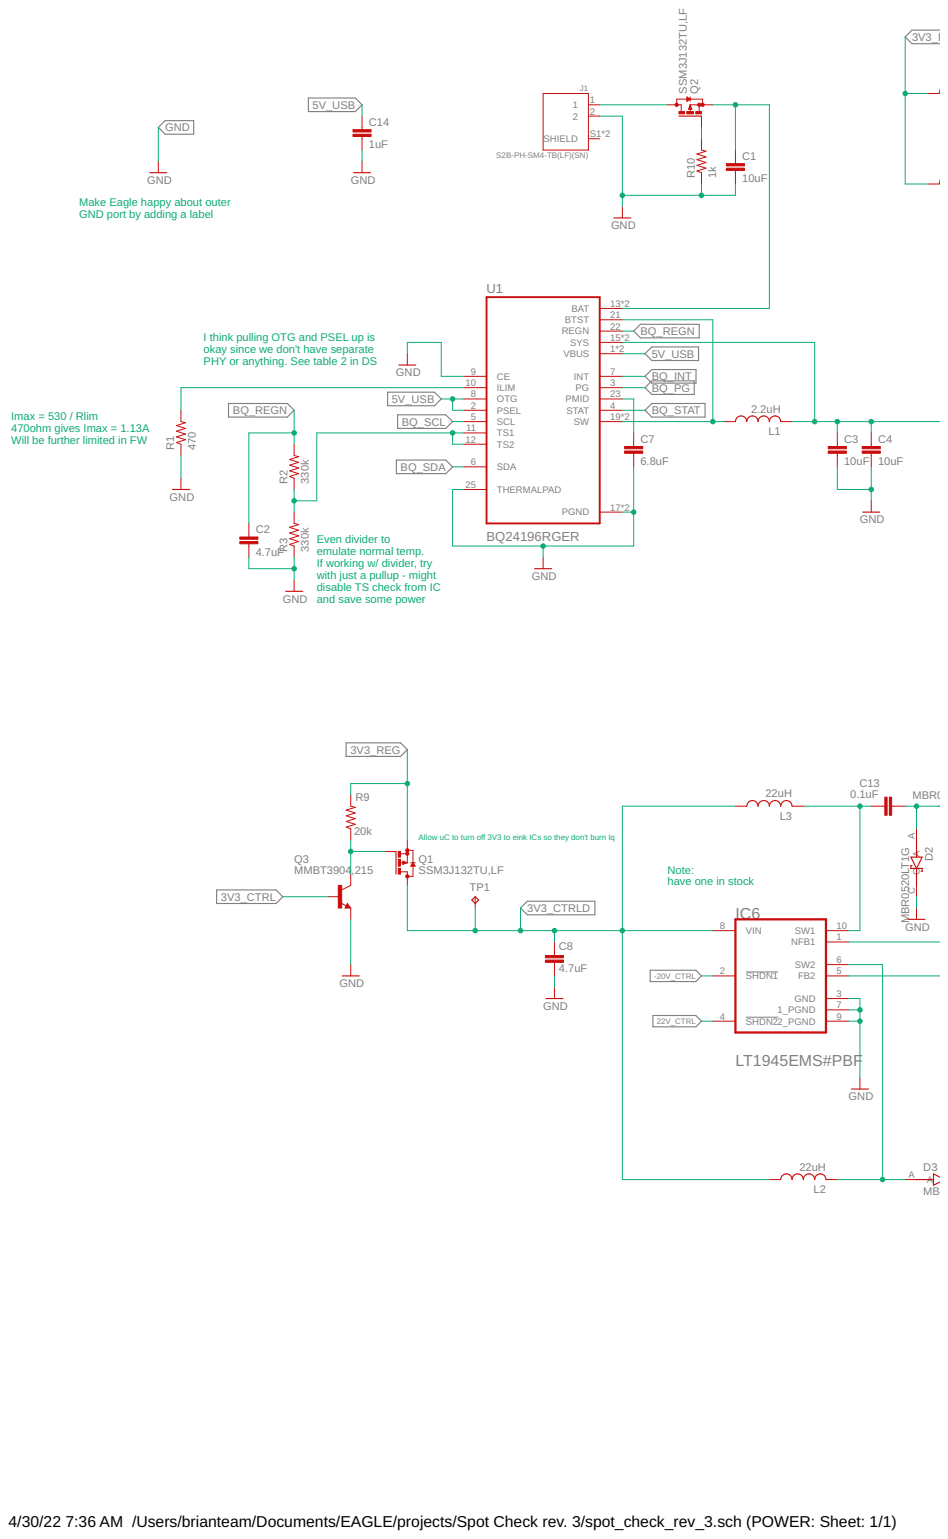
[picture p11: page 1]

Make Eagle happy about outer GND port by adding a label

22 SYS BQ_REGN

I think pulling OTG and PSEL up is okay since we don't have separate PHY or anything. See table 2 in DS

7 PG 3 PMID 23 STAT

Imax = 530 / Rlim
470ohm gives Imax = 1.13A
Will be further limited in FW

Even divider to
emulate normal temp.
If working w/ divider, try with just a pullup - might
disable TS check from IC
and save some power

Allow uC to turn off 3V3 to eink ICs so they don't burn Iq

Note: have one in stock

4/30/22 7:36 AM /Users/brianteam/Documents/EAGLE/projects/Spot Check rev. 3/spot_check_rev_3.sch (POWER: Sheet: 1/1)

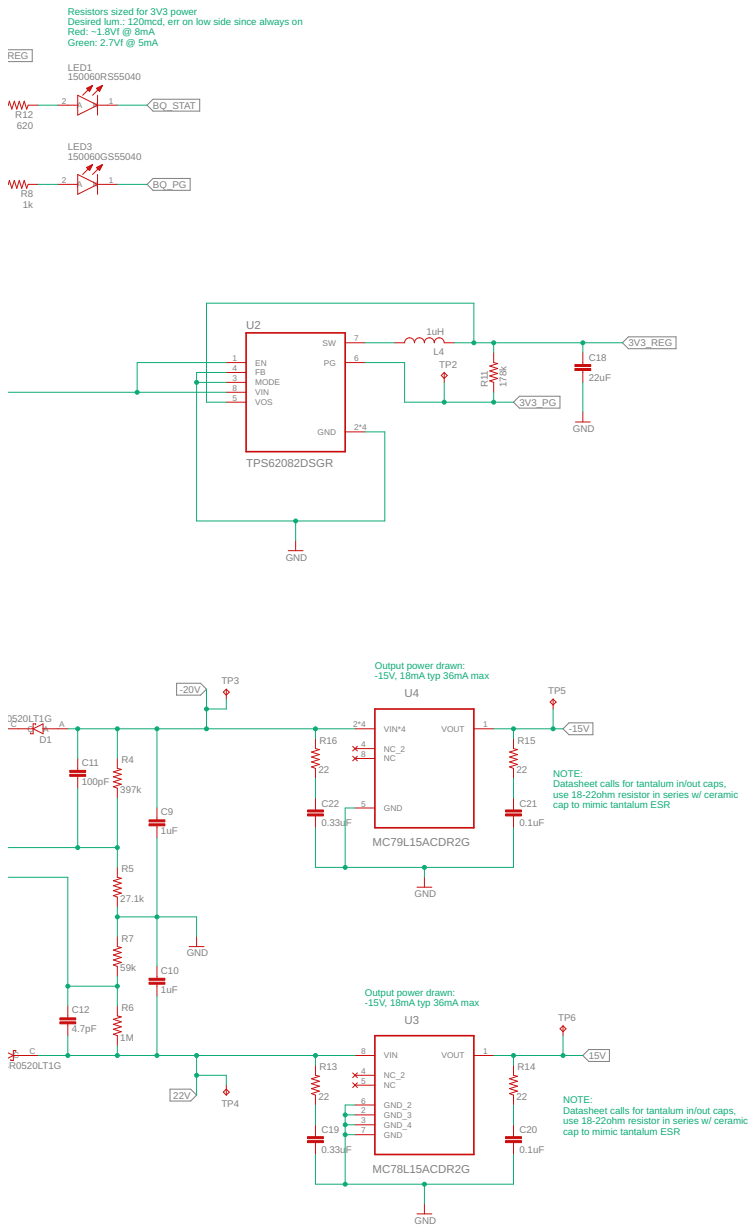
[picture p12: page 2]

Resistors sized for 3V3 power Desired lum.: 120mcd, err on low side since always on Red: ~1.8Vf @ 8mA

Output power drawn: -15V, 18mA typ 36mA max

NOTE: Datasheet calls for tantalum in/out caps, use 18-22ohm resistor in series w/ ceramic

cap to mimic tantalum ESR

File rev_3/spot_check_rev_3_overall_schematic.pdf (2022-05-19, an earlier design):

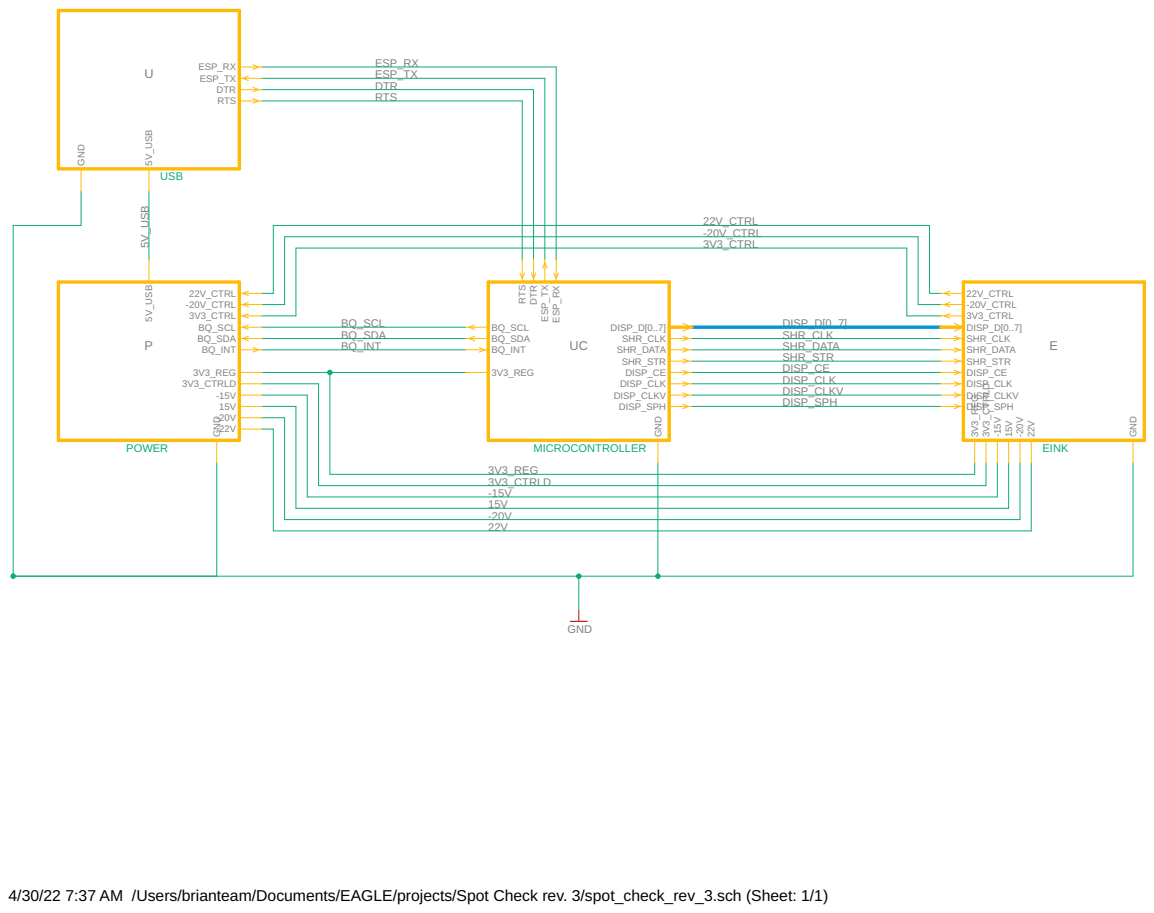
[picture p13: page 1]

-20V_CTRL
3V3_CTRL

BQ_SDA | SHR_CLK
BQ_INT | SHR_DATA

4/30/22 7:37 AM /Users/brianteam/Documents/EAGLE/projects/Spot Check rev. 3/spot_check_rev_3.sch (Sheet: 1/1)

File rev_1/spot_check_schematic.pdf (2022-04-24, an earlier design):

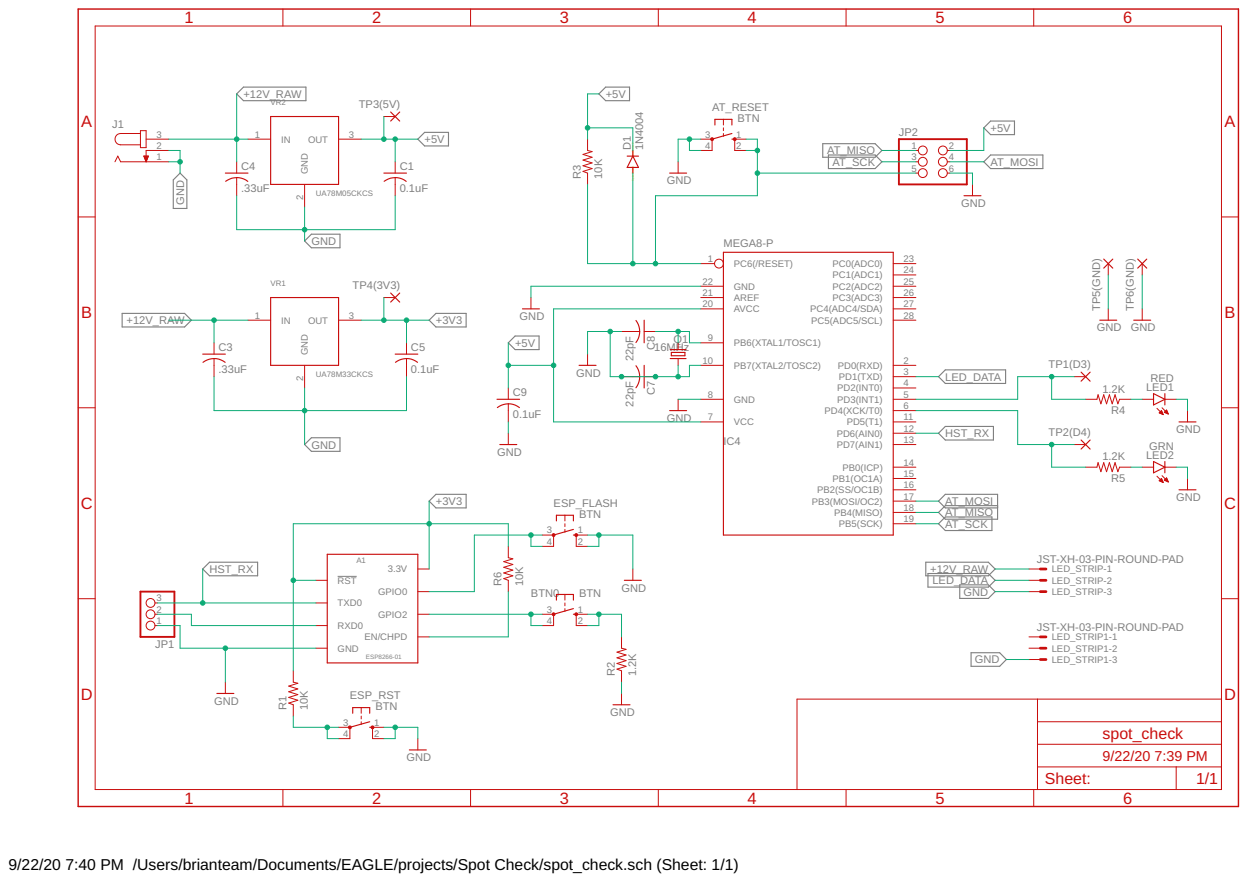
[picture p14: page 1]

9/22/20 7:40 PM /Users/brianteam/Documents/EAGLE/projects/Spot Check/spot_check.sch (Sheet: 1/1)

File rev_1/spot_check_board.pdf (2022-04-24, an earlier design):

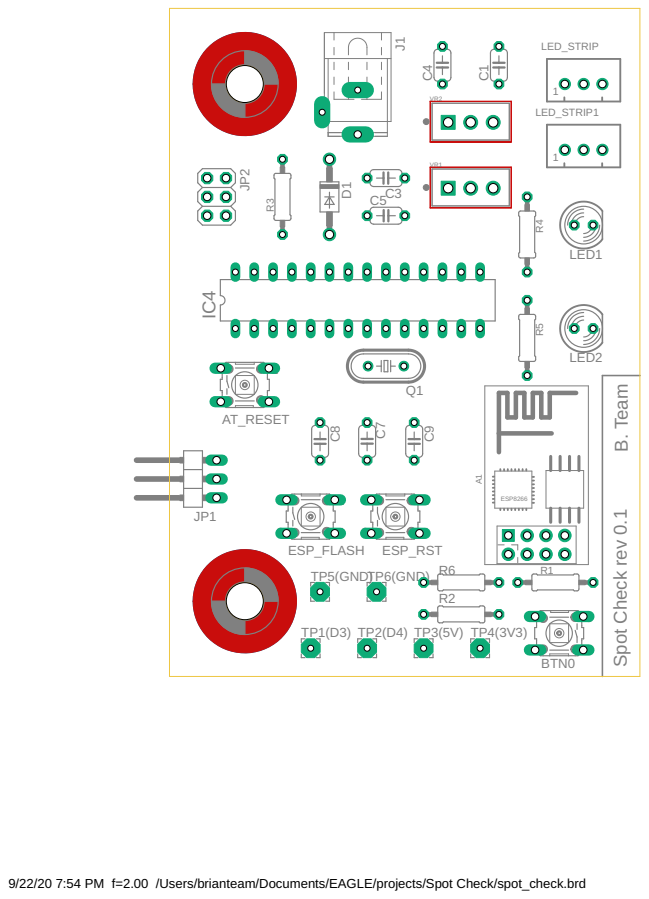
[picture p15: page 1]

9/22/20 7:54 PM f=2.00 /Users/brianteam/Documents/EAGLE/projects/Spot Check/spot_check.brd

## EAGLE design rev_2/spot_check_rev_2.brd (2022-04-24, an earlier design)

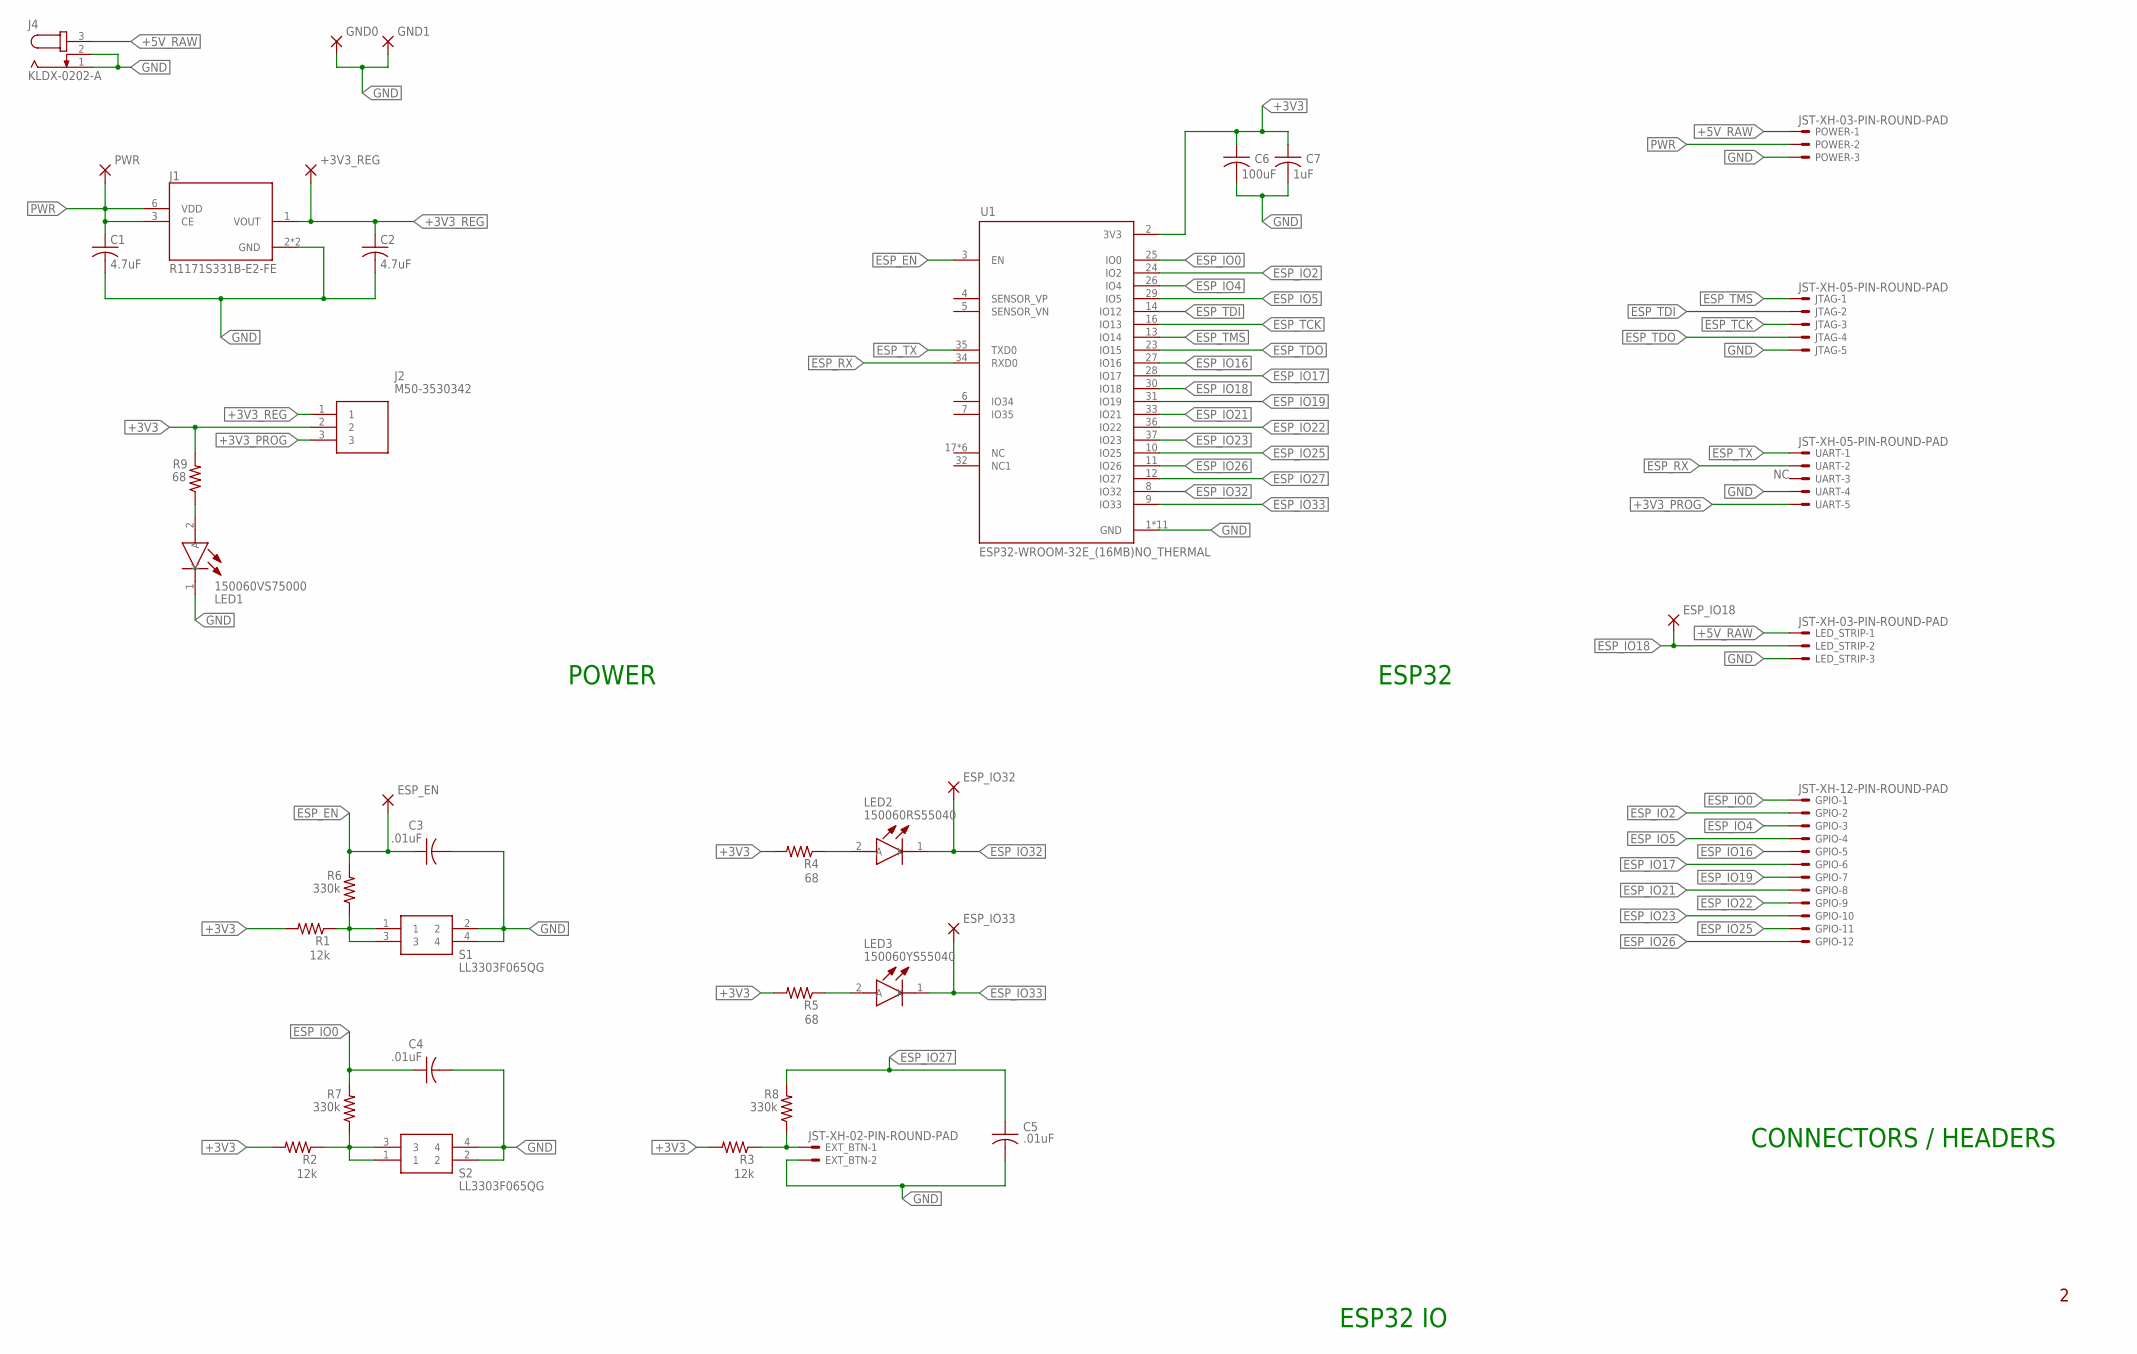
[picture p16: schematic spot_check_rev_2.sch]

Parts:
+3V3_REG: TP; 2,54/1,1
C1, C2: 4.7uF; C0805
C3, C4, C5: .01uF; C0805
C6: 100uF; C0805
C7: 1uF; C0805
ESP_EN: TP; 2,54/1,1
ESP_IO18, ESP_IO32, ESP_IO33: TP; 2,54/1,1
EXT_BTN: JST-XH-02-PIN-ROUND-PAD; JST-XH-02-PACKAGE-ROUND-PAD
GND0, GND1: TP; 2,54/1,1
GPIO: JST-XH-12-PIN-ROUND-PAD; JST-XH-12-PACKAGE-ROUND-PAD
J1: R1171S331B-E2-FE; REG_R1171S421B-E2-FE
J2: M50-3530342; HDRV3W40P0X127_1X3_381X210X430
J4: KLDX-0202-A; SPC4077
JTAG: JST-XH-05-PIN-ROUND-PAD; JST-XH-05-PACKAGE-ROUND-PAD
LED1: 150060VS75000; LEDC1608X80N
LED2: 150060RS55040; LEDC1608X80N
LED3: 150060YS55040; LEDC1608X80N
LED_STRIP: JST-XH-03-PIN-ROUND-PAD; JST-XH-03-PACKAGE-ROUND-PAD
POWER: JST-XH-03-PIN-ROUND-PAD; JST-XH-03-PACKAGE-ROUND-PAD
PWR: TP; 2,54/1,1
R1, R2, R3: 12k; R0805
R4, R5, R9: 68; R0805
R6, R7, R8: 330k; R0805
S1, S2: LL3303F065QG
U1: ESP32-WROOM-32E_(16MB)NO_THERMAL; MODULE_ESP32-WROOM-32E_(16MB)
UART: JST-XH-05-PIN-ROUND-PAD; JST-XH-05-PACKAGE-ROUND-PAD

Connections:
+3V3: C6.1, C7.1, J2.2, R1.2, R2.2, R3.2, R4.2, R5.2, R9.2, U1.2 (3V3)
+3V3_PROG: J2.3, UART.5
+3V3_REG: +3V3_REG.1, C2.1, J1.1 (VOUT), J2.1
+5V_RAW: J4.3, LED_STRIP.1, POWER.1
ESP_EN: C3.1, ESP_EN.1, R6.2, U1.3 (EN)
ESP_IO0: C4.1, GPIO.1, R7.2, U1.25 (IO0)
ESP_IO2: GPIO.2, U1.24 (IO2)
ESP_IO4: GPIO.3, U1.26 (IO4)
ESP_IO5: GPIO.4, U1.29 (IO5)
ESP_IO16: GPIO.5, U1.27 (IO16)
ESP_IO17: GPIO.6, U1.28 (IO17)
ESP_IO18: ESP_IO18.1, LED_STRIP.2, U1.30 (IO18)
ESP_IO19: GPIO.7, U1.31 (IO19)
ESP_IO21: GPIO.8, U1.33 (IO21)
ESP_IO22: GPIO.9, U1.36 (IO22)
ESP_IO23: GPIO.10, U1.37 (IO23)
ESP_IO25: GPIO.11, U1.10 (IO25)
ESP_IO26: GPIO.12, U1.11 (IO26)
ESP_IO27: C5.1, R8.2, U1.12 (IO27)
ESP_IO32: ESP_IO32.1, LED2.1 (K), U1.8 (IO32)
ESP_IO33: ESP_IO33.1, LED3.1 (K), U1.9 (IO33)
ESP_RX: U1.34 (RXD0), UART.2
ESP_TCK: JTAG.3, U1.16 (IO13)
ESP_TDI: JTAG.2, U1.14 (IO12)
ESP_TDO: JTAG.4, U1.23 (IO15)
ESP_TMS: JTAG.1, U1.13 (IO14)
ESP_TX: U1.35 (TXD0), UART.1
GND: C1.2, C2.2, C3.2, C4.2, C5.2, C6.2, C7.2, EXT_BTN.2, GND0.1, GND1.1, J1.2 (GND), J1.5 (GND), J4.1, J4.2, JTAG.5, LED1.1 (K), LED_STRIP.3, POWER.3, S1.2, S1.4, S2.2, S2.4, U1.1 (GND), U1.15 (GND), U1.38 (GND), U1.39_1 (GND), U1.39_3 (GND), U1.39_4 (GND), U1.39_6 (GND), U1.39_7 (GND), U1.39_9 (GND), U1.39_13 (GND), U1.39_18 (GND), UART.4
unnamed: EXT_BTN.1, R3.1, R8.1
unnamed: LED2.2 (A), R4.1
unnamed: LED3.2 (A), R5.1
unnamed: LED1.2 (A), R9.1
unnamed: R1.1, R6.1, S1.1, S1.3
unnamed: R2.1, R7.1, S2.1, S2.3
PWR: C1.1, J1.3 (CE), J1.6 (VDD), POWER.2, PWR.1

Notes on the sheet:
POWER
ESP32
ESP32 IO
CONNECTORS / HEADERS

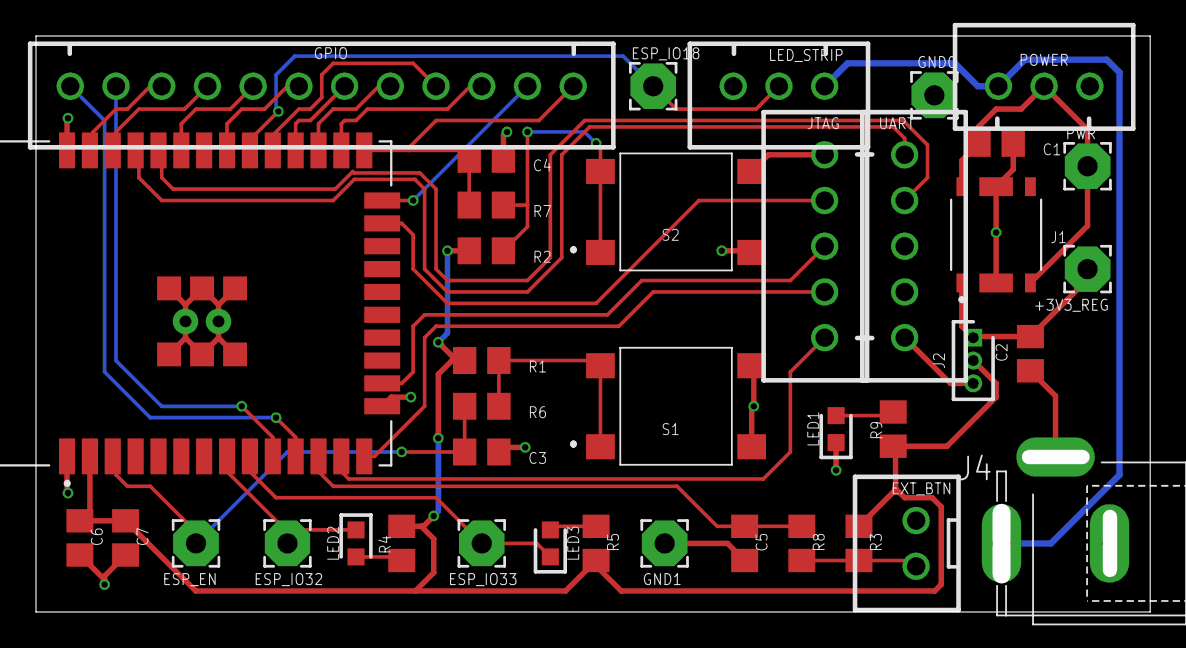
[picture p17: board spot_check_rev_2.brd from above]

Board: 2 copper layers, 61.9 x 32.0 mm, 39 parts (0 on the bottom side), 35 nets.

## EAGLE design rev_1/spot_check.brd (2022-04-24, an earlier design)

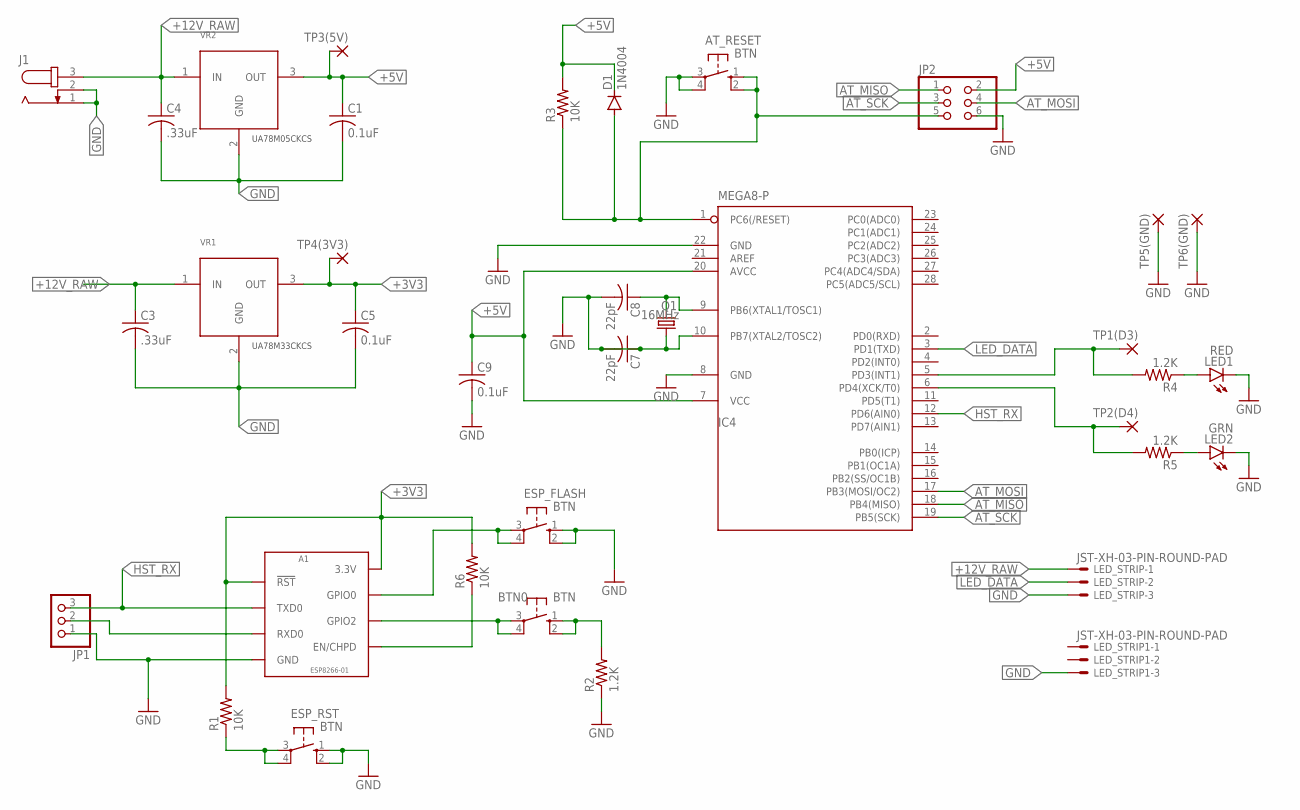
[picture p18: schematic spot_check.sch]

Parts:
A1: ESP8266-01; ESP8266_ESP-01_NO-SILKSCREEN
AT_RESET: BTN; B3F-10XX
BTN0: BTN; B3F-10XX
C1, C5, C9: 0.1uF; C050-024X044
C3, C4: .33uF; C050-024X044
C7, C8: 22pF; C050-024X044
D1: 1N4004; DO41-10
ESP_FLASH: BTN; B3F-10XX
ESP_RST: BTN; B3F-10XX
IC4: MEGA8-P; DIL28-3
J1: JACK-PLUG1; SPC4078
JP1: PINHD-1X3/90; 1X03/90
JP2: PINHD-2X3; 2X03
LED1: RED; LED5MM
LED2: GRN; LED5MM
LED_STRIP, LED_STRIP1: JST-XH-03-PIN-ROUND-PAD; JST-XH-03-PACKAGE-ROUND-PAD
Q1: 16MHz; HC49/S
R1, R3, R6: 10K; 0207/10
R2, R4, R5: 1.2K; 0207/10
TP1(D3), TP2(D4), TP3(5V), TP4(3V3), TP5(GND), TP6(GND): 2,54/0,8
VR1: UA78M33CKCS; TO-220-3
VR2: UA78M05CKCS; TO-220-3

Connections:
+3V3: A1.3V3 (3.3V), A1.RST (!RST!), C5.1, R1.2, R6.2, TP4(3V3).1, VR1.3 (OUT)
+5V: C1.1, C9.1, D1.C, IC4.7 (VCC), IC4.20 (AVCC), JP2.2, R3.2, TP3(5V).1, VR2.3 (OUT)
+12V_RAW: C3.1, C4.1, J1.3, LED_STRIP.1, VR1.1 (IN), VR2.1 (IN)
AT_MISO: IC4.18 (PB4(MISO)), JP2.1
AT_MOSI: IC4.17 (PB3(MOSI/OC2)), JP2.4
AT_SCK: IC4.19 (PB5(SCK)), JP2.3
GND: A1.GND, AT_RESET.3, AT_RESET.4 (P1), C1.2, C3.2, C4.2, C5.2, C7.1, C7.2, C8.2, C9.2, ESP_FLASH.1 (S), ESP_FLASH.2 (S1), ESP_RST.1 (S), ESP_RST.2 (S1), IC4.8 (GND), IC4.10 (PB7(XTAL2/TOSC2)), IC4.22 (GND), J1.1, J1.2, JP1.1, JP2.6, LED1.K (C), LED2.K (C), LED_STRIP.3, LED_STRIP1.3, Q1.1, R2.1, TP5(GND).1, TP6(GND).1, VR1.2 (GND), VR2.2 (GND)
HST_RX: A1.TX (TXD0), IC4.12 (PD6(AIN0)), JP1.3
HST_TX: A1.RX (RXD0), JP1.2
LED_DATA: IC4.3 (PD1(TXD)), LED_STRIP.2
unnamed: A1.EN/CH_PD (EN/CHPD), R6.1
unnamed: A1.GPIO2, BTN0.3, BTN0.4 (P1)
unnamed: LED1.A, R4.1
unnamed: BTN0.1 (S), BTN0.2 (S1), R2.2
unnamed: A1.GPIO0, ESP_FLASH.3, ESP_FLASH.4 (P1)
unnamed: LED2.A, R5.1
unnamed: C8.1, IC4.9 (PB6(XTAL1/TOSC1)), Q1.2
unnamed: AT_RESET.1 (S), AT_RESET.2 (S1), D1.A, IC4.1 (PC6(/RESET)), JP2.5, R3.1
unnamed: ESP_RST.3, ESP_RST.4 (P1), R1.1
TP1(D3): IC4.5 (PD3(INT1)), R4.2, TP1(D3).1
TP2(D4): IC4.6 (PD4(XCK/T0)), R5.2, TP2(D4).1

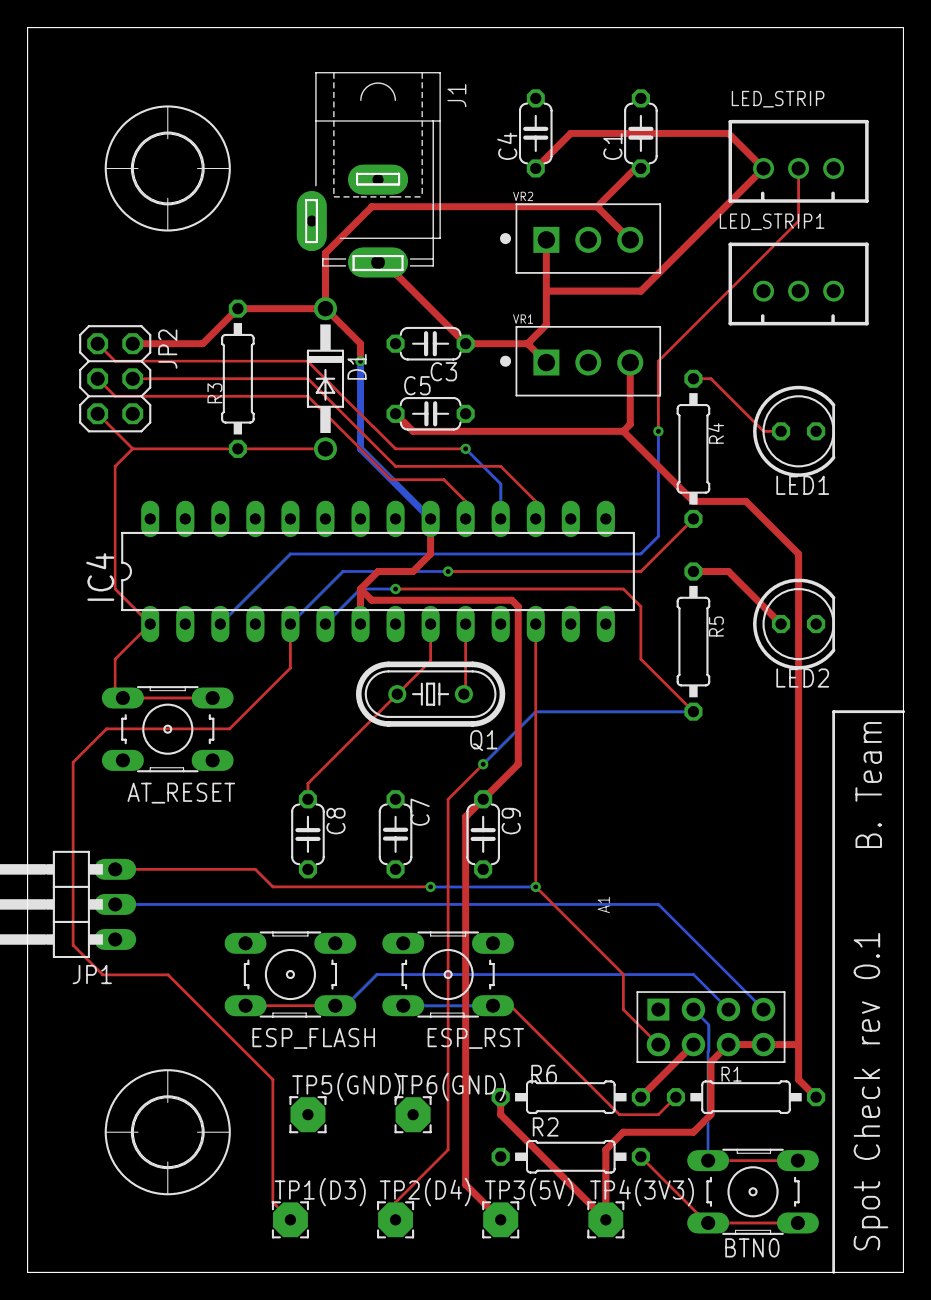
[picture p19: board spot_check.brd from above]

Board: 2 copper layers, 63.5 x 90.2 mm, 38 parts (0 on the bottom side), 21 nets.

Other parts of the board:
U$1, U$2: 5,0

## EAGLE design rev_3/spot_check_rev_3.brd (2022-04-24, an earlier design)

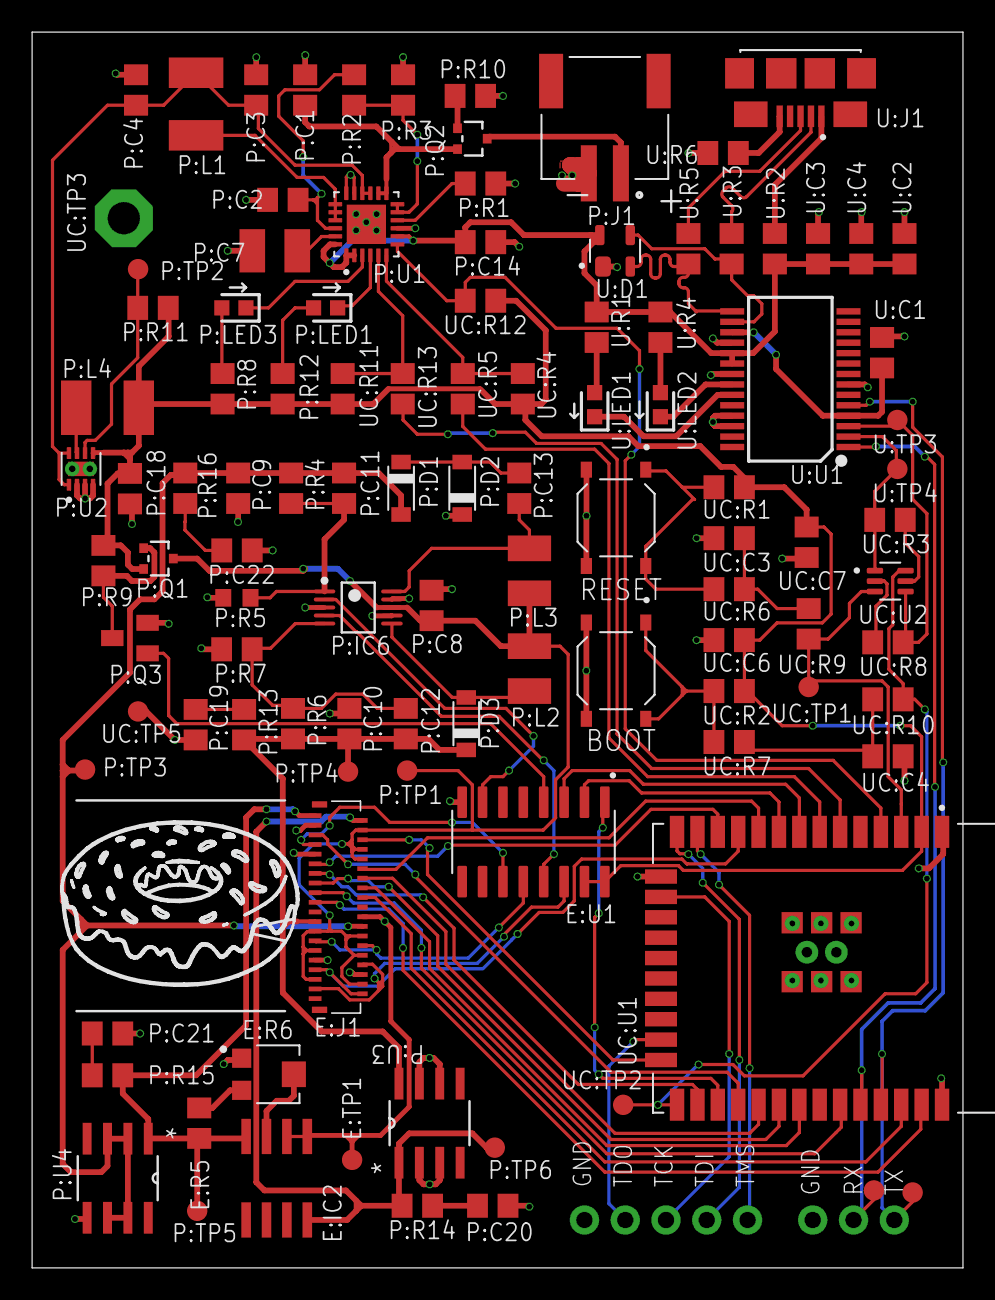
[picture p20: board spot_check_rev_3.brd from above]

Board: 2 copper layers, 58.0 x 77.0 mm, 109 parts (0 on the bottom side), 89 nets.

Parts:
E:IC2: LM358DR; SO08
E:J1: FH26W-39S-0.3SHW_05_; FH26W39S03SHW05
E:R5: 20k; R0805
E:R6: 10k; TRIM_TC33X-2-333E
E:TP1: TPB1,27; B1,27
E:U1: CD74HC4094M; SOIC127P600X175-16N
P:C1, P:C3, P:C4: 10uF; C0805
P:C2, P:C8: 4.7uF; C0805
P:C7: 6.8uF; C1210
P:C9, P:C10, P:C14: 1uF; C0805
P:C11: 100pF; C0805
P:C12: 4.7pF; C0805
P:C13, P:C20, P:C21: 0.1uF; C0805
P:C18: 22uF; C0805
P:C19, P:C22: 0.33uF; C0805
P:D1, P:D2, P:D3: MBR0520LT1G; SOD3716X135N
P:IC6: LINEAR_TECHNOLOGY_LT1945EMS#PBFLINEAR_TECHNOLOGY_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; LINEAR_TECHNOLOGY_LT1945EMS#PBF_0
P:J1: S2B-PH-SM4-TB(LF)(SN); JST_S2B-PH-SM4-TB(LF)(SN)
P:L1: 2.2uH; L1812
P:L2, P:L3: 22uH; C1210
P:L4: 1uH; L1812
P:LED1: 150060RS55040; LEDC1608X80N
P:LED3: 150060GS55040; LEDC1608X80N
P:Q1, P:Q2: SSM3J132TU,LF; SOT323
P:Q3: MMBT3904,215; SOT23
P:R1: 470; R0805
P:R2, P:R3: 330k; R0805
P:R4: 397k; R0805
P:R5: 27.1k; R0603
P:R6: 1M; R0805
P:R7: 59k; R0805
P:R8, P:R10: 1k; R0805
P:R9: 20k; R0805
P:R11: 178k; R0805
P:R12: 620; R0805
P:R13, P:R14, P:R15, P:R16: 22; R0805
P:TP1, P:TP2, P:TP3, P:TP4, P:TP5, P:TP6: TPB1,27; B1,27
P:U1: BQ24196RGER; QFN50P400X400X100-25N
P:U2: TPS62082DSGR; SON50P200X200X80-9N
P:U3: MC78L15ACDR2G; SOIC127P600X175-8N
P:U4: MC79L15ACDR2G; SOIC127P600X175-8N
U:C1, U:C4: 100nF; C0805
U:C2: 4.7uF; C0805
U:C3: 10nF; C0805
U:D1: DRTR5V0U2SR-7; SOT143
U:J1: 10118192-0002LF; AMPHENOL_10118192-0002LF
U:LED1: 150060YS55040; LEDC1608X80N
U:LED2: 150060BS55040; LEDC1608X80N
U:R1: 270; R0805
U:R2, U:R3, U:R5, U:R6: 0; R0805
U:R4: 330; R0805
U:TP1, U:TP2, U:TP3, U:TP4: TPB1,27; B1,27
U:U1: INTERFACE-FT232RL(SSOP28); SSOP28-0.65-10.2X5.2MM
UC:C3, UC:C4: .01uF; C0805
UC:C6: 22uF; C0805
UC:C7: 1uF; C0805
UC:JTAG: JST-XH-05-PIN-ROUND-PAD; JST-XH-05-PACKAGE-ROUND-PAD
UC:R1, UC:R2: 12k; R0805
UC:R3, UC:R8: 10k; R0805
UC:R4, UC:R11, UC:R12: 4.7k; R0805
UC:R5, UC:R9, UC:R10, UC:R13: 0; R0805
UC:R6, UC:R7: 330k; R0805
UC:S1, UC:S2: PTS526_SM08_SMTR2_LFS; SW_PTS526_SM08_SMTR2_LFS
UC:TP1, UC:TP2, UC:TP5: TPB1,27; B1,27
UC:TP3: TPPAD1-20; P1-20
UC:U1: ESP32-WROOM-32E_(16MB); MODULE_ESP32-WROOM-32E_(16MB)
UC:U2: BC848CDW1T1G; SOT65P210X110-6N
UC:X1: JST-XH-03-PIN-ROUND-PAD; JST-XH-03-PACKAGE-ROUND-PAD

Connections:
3V3_CTRL: E:U1.4, P:Q3.1
3V3_CTRLD: E:J1.4, E:J1.8, E:J1.10, E:J1.25, E:J1.26, E:J1.29, E:J1.30, E:J1.35, E:J1.36, P:C8.1, P:IC6.8, P:L2.1, P:L3.1, P:Q1.3, P:TP1.TP
3V3_REG: E:U1.15, E:U1.16, P:C18.1, P:L4.2, P:Q1.2, P:R8.2, P:R9.2, P:R11.2, P:R12.2, P:U2.5, UC:C6.1, UC:C7.1, UC:R1.2, UC:R2.2, UC:R4.1, UC:R11.1, UC:R12.1, UC:U1.2
5V_USB: P:C14.1, P:U1.1, P:U1.2, P:U1.8, P:U1.24, U:C2.1, U:C3.1, U:C4.1, U:D1.4, U:R1.2, U:R2.2, U:R4.2, U:U1.19, U:U1.20
15V: E:IC2.8, E:J1.2, P:R14.2, P:TP6.TP, P:U3.1
22V: E:J1.23, P:C10.2, P:C12.2, P:D3.C, P:R6.1, P:R13.2, P:TP4.TP, P:U3.8
22V_CTRL: E:U1.13, P:IC6.4
-15V: E:IC2.4, E:J1.1, E:R5.1, P:R15.2, P:TP5.TP, P:U4.1
-20V: E:J1.24, P:C9.1, P:C11.1, P:D1.A, P:R4.2, P:R16.2, P:TP3.TP, P:U4.2, P:U4.3, P:U4.6, P:U4.7
-20V_CTRL: E:U1.7, P:IC6.2
BQ_INT: P:U1.7, UC:R12.2, UC:U1.4
BQ_SCL: P:U1.5, UC:R11.2, UC:R13.1
BQ_SDA: P:U1.6, UC:R4.2, UC:R5.1
DISP_CE: E:J1.6, UC:U1.24
DISP_CLK: E:J1.5, UC:U1.28
DISP_CLKV: E:J1.33, E:J1.38, UC:U1.11
DISP_D0: E:J1.12, UC:U1.10
DISP_D1: E:J1.13, UC:U1.26
DISP_D2: E:J1.14, UC:U1.29
DISP_D3: E:J1.15, UC:U1.30
DISP_D4: E:J1.16, UC:U1.31
DISP_D5: E:J1.17, UC:U1.33
DISP_D6: E:J1.18, UC:U1.36
DISP_D7: E:J1.19, UC:U1.37
DISP_SPH: E:J1.11, UC:U1.12
DTR: U:TP4.TP, U:U1.2, UC:R3.2, UC:U2.1
E:DISP_GMODE: E:J1.27, E:J1.28, E:U1.12
E:DISP_OE: E:J1.7, E:U1.11
E:DISP_SPV: E:J1.32, E:J1.37, E:U1.14
E:DISP_VCOMMON: E:IC2.1, E:IC2.2, E:J1.22, E:TP1.TP
E:N$2: E:R5.2, E:R6.3
E:N$3: E:IC2.3, E:R6.2
ESP_RX: U:TP1.TP, U:U1.1, UC:U1.34, UC:X1.2
ESP_TX: U:TP2.TP, U:U1.5, UC:U1.35, UC:X1.1
GND: E:J1.3, E:J1.9, E:J1.31, E:J1.34, E:R6.1, E:U1.8, P:C1.2, P:C2.2, P:C3.2, P:C4.2, P:C7.2, P:C8.2, P:C9.2, P:C10.1, P:C14.2, P:C18.2, P:C19.2, P:C20.2, P:C21.2, P:C22.2, P:D2.C, P:IC6.3, P:IC6.7, P:IC6.9, P:J1.2, P:Q3.2, P:R1.1, P:R3.1, P:R5.1, P:R7.2, P:R10.1, P:U1.9, P:U1.17, P:U1.18, P:U1.25, P:U2.2, P:U2.3, P:U2.4, P:U2.9, P:U2.9_1, P:U2.9_2, P:U3.2, P:U3.3, P:U3.6, P:U3.7, P:U4.5, U:C1.2, U:C2.2, U:C3.2, U:C4.2, U:D1.1, U:R6.2, U:U1.7, U:U1.18, U:U1.21, U:U1.25, U:U1.26, UC:C3.2, UC:C4.2, UC:C6.2, UC:C7.2, UC:JTAG.5, UC:S1.3, UC:S1.4, UC:S2.3, UC:S2.4, UC:TP3.TP, UC:TP5.TP, UC:U1.1, UC:U1.15, UC:U1.38, UC:X1.3
P:3V3_PG: P:R11.1, P:TP2.TP, P:U2.6
P:BQ_PG: P:LED3.1, P:U1.3
P:BQ_REGN: P:C2.1, P:R2.2, P:U1.22
P:BQ_STAT: P:LED1.1, P:U1.4
P:N$1: P:C1.1, P:Q2.2, P:U1.13, P:U1.14
P:N$2: P:R2.1, P:R3.2, P:U1.11, P:U1.12
P:N$3: P:L1.1, P:U1.19, P:U1.20, P:U1.21
P:N$4: P:J1.1, P:Q2.3
P:N$5: P:C7.1, P:U1.23
P:N$6: P:R1.2, P:U1.10
P:N$7: P:LED3.2, P:R8.1
P:N$8: P:C3.1, P:C4.1, P:L1.2, P:U1.15, P:U1.16, P:U2.1, P:U2.8
P:N$9: P:Q2.1, P:R10.2
P:N$10: P:C12.1, P:IC6.5, P:R6.2, P:R7.1
P:N$11: P:L4.1, P:U2.7
P:N$12: P:LED1.2, P:R12.1
P:N$13: P:D3.A, P:IC6.6, P:L2.2
P:N$14: P:C13.2, P:D1.C, P:D2.A
P:N$15: P:Q1.1, P:Q3.3, P:R9.1
P:N$16: P:C13.1, P:IC6.10, P:L3.2
P:N$17: P:C11.2, P:IC6.1, P:R4.1, P:R5.2
P:N$19: P:C22.1, P:R16.1
P:N$20: P:C21.1, P:R15.1
P:N$21: P:C20.1, P:R14.1
P:N$22: P:C19.1, P:R13.1
RTS: U:TP3.TP, U:U1.3, UC:R8.2, UC:U2.4
SHR_CLK: E:U1.3, UC:U1.8
SHR_DATA: E:U1.2, UC:U1.9
SHR_STR: E:U1.1, UC:U1.27
U:FT232_RX_IND: U:LED2.1, U:U1.22
U:FT232_TX_IND: U:LED1.1, U:U1.23
U:N$1: U:LED1.2, U:R1.1
U:N$2: U:LED2.2, U:R4.1
U:N$3: U:J1.1, U:R2.1
U:N$4: U:C1.1, U:U1.4, U:U1.17
U:N$7: U:J1.5, U:R6.1
U:USBD1_N: U:J1.2, U:R3.1
U:USBD1_P: U:J1.3, U:R5.1
U:USBD2_N: U:D1.3, U:R3.2, U:U1.16
U:USBD2_P: U:D1.2, U:R5.2, U:U1.15
UC:ESP_EN: UC:R9.2, UC:TP1.TP, UC:U1.3, UC:U2.3
UC:ESP_IO0: UC:R10.2, UC:TP2.TP, UC:U1.25, UC:U2.6
UC:ESP_TCK: UC:JTAG.3, UC:U1.16
UC:ESP_TDI: UC:JTAG.2, UC:U1.14
UC:ESP_TDO: UC:JTAG.4, UC:U1.23
UC:ESP_TMS: UC:JTAG.1, UC:U1.13
UC:N$1: UC:R3.1, UC:U2.5
UC:N$2: UC:R13.2, UC:U1.6
UC:N$3: UC:R5.2, UC:U1.7
UC:N$4: UC:R8.1, UC:U2.2
UC:N$5: UC:R1.1, UC:R6.1, UC:S1.1, UC:S1.2
UC:N$6: UC:R2.1, UC:R7.1, UC:S2.1, UC:S2.2
UC:N$7: UC:C4.1, UC:R7.2, UC:R10.1
UC:N$9: UC:C3.1, UC:R6.2, UC:R9.1

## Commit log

2022-04-24 Committing rev 3 files matching rev 3 mfgd PCB
    [spot_check_rev_3.brd, spot_check_rev_3.sch]
2022-04-24 Move to nested dirs for each rev
    [spot_check_rev_3.brd, spot_check_rev_3.sch]
2022-04-24 Symlinks don't work 🤦🏼
    [spot_check_rev_3.brd, spot_check_rev_3.sch]
2022-04-24 Add gerber zip along w/ BOM and datasheets
    [rev_3_bom.xlsx]
2022-04-24 Add rev_1 and rev_2 files
    [exported_bom_spot_check_rev_2.csv, rev_2_bom.xlsx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]
2022-05-19 Add rev 3 schematic pdfs
2022-05-19 Add all rev 3.1 project files, datasheets, gerbers, and schematics
    [rev_3_1_bom.xlsx]
2022-10-09 Add newest gerber zip for rev 3.1
2022-10-09 Add photos and update readme for board pictures
    [gerber_job.gbrjob, spot_check_rev_3_1.GBL, spot_check_rev_3_1.GBO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]
